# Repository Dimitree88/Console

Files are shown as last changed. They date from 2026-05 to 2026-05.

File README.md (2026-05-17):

# CONSOLE — Reference Specification

> Analog mixing console design — full signal-flow reference and
> implementation record. This is a multi-file documentation project;
> this README is the entry point.
>
> **For Claude sessions:** working rules and session-start procedure
> live in `CLAUDE.md`, which is loaded automatically.

---

## What this project is

CONSOLE is a fully analog mixing console. 24 mono input channels,
**4 stereo AUX returns**, 3 stereo groups, 4 AUX masters, CUE master,
Main Mix master with parallel SSL-style bus compression, monitor
section with AFL/PFL solo logic.

Firmware is out of scope; this documents the analog signal flow and
the implementation decisions made during circuit design.

---

## Mental model (one paragraph)

CONSOLE is a 24+4+3 analog desk (24 mono channels, 4 stereo AUX
returns, 3 stereo sub-groups) feeding a Main stereo bus with
parallel SSL-style compression. Channel strips follow a conventional
flow (balanced in → gain → HPF → insert → meter and PFL taps →
MUTE electronic switch → fader → +10 dB post-amp → pan → routing)
with two distinctive design choices: (1) dual balanced inputs A/B
with a full-differential Channel Output from Input A for ADC tracking;
(2) every channel has 4 AUX sends implemented as dual-gang pots that
simultaneously drive a pre-fader and a post-fader mono bus, giving
8 AUX buses total. The 4 stereo AUX returns are routing-only
(no Post-Fader Output to the outside, no Insert, no AUX send) — they
contribute only to internal buses (Main / Groups / AFL / CUE / PFL
stereo). Groups offer per-AUX split-or-mono mode switches so a
stereo group can feed stereo AUX pairs either as L/R split or as
mono premix. The master section's distinguishing features are the
parallel compression on the main bus (dry fader + SSL-style
compressor + wet fader → summed output) and an "in front balance"
pot that mixes an attenuated main mix behind the AFL so the engineer
always hears the context. Digital control is limited to hard-muting /
enabling electronic switches for ACTIVE, SOLO, and AFL — no VCAs,
no recall, no automation. Talkback, tone oscillators, and master
master meters are deliberately absent.

---

## File map

| File | Contents |
|---|---|
| `CLAUDE.md` | working rules for Claude — required reading at session start, loaded automatically |
| `README.md` | this file — entry point, file map, project status snapshot |
| `00-conventions.md` | design conventions + electrical/implementation conventions (power supplies, grounds, packages, default audio opamp, default topologies for EMI filter, impedance-balanced output, switches+LEDs, …) |
| `01-bus-inventory.md` | enumeration of every bus in the console (stereo + mono) and what feeds each one |
| `02-mono-channel.md` | §2 — mono input channel signal flow + Implementation details (Blocks 1, 2, …) |
| `03-aux-return.md` | §3 — stereo AUX returns (×4, identical) |
| `04-group.md` | §4 — stereo groups (×3) |
| `05-aux-master.md` | §5 — AUX master (×4) |
| `06-cue-master.md` | §6 — CUE master |
| `07-main-mix.md` | §7 — Main Mix master + parallel compression |
| `08-monitor.md` | §8 — Master monitor section |
| `09-not-present.md` | §9 — features deliberately NOT in CONSOLE |
| `10-open-tbd.md` | §10 — items deliberately unresolved at this stage |
| `11-digital-io.md` | §11 — running count of relays, LEDs, and pushbuttons; keep in sync with design changes |

(Sections §11 "Counts" lives at the end of `01-bus-inventory.md`.
The one-paragraph mental model lives at the top of this README.)

---

## Section file structure

Every main section file (`02-mono-channel.md` through `08-monitor.md`)
contains both the **conceptual signal flow** description and an
**Implementation details** subsection. Implementation details grow
over time as concrete circuit choices are made, organized into
"Blocks" (Block 1, Block 2, …) corresponding to chunks of the
signal path that were finalized in a single conversation. The Block
template and editing rules live in `CLAUDE.md`.

---

## Project status snapshot

(Update this section briefly at the end of major conversations, so
future Claude can immediately see where things stand.)

- Mono channel: signal flow conceptually complete. Implementation:
  - Block 1 (input stage → SOURCE switch + DIRECT OUT
    SELECT relay on input PCB) FINALIZED — SOURCE
    relay-driven (AGQ210A03 latching) with momentary pushbutton +
    firmware bipolar pulse; primary motivation: enables global
    master A/B flip across all 24 channels. Channel Output SELECT
    relay added: makes the Channel Output TRS jack switchable between
    Input A full-differential and channel PRE/POST impedance-
    balanced signal (see Block 8).
  - Block 2 (HPF + Insert Send/Return + jack PCB) FINALIZED.
  - Block 3 (meter buffer concept + PFL switch + MUTE) FINALIZED —
    MUTE relay (AGQ210A03) now configured **series + shunt** (contact
    set 1 = series switch, contact set 2 = shunt PRE-FADER to AGND
    when muted), replacing the earlier paralleled-contacts approach.
    Meter buffer implementation (NE5532 + DG419) finalized in Block 10.
  - Block 4 (pre-fader node + fader PCB + post-fader amp +10 dB +
    AUX/CUE pre & post sends) FINALIZED.
  - Block 5 (active pan, Self-style) FINALIZED — Self canonical
    values (R_FB = 2.2 kΩ, center dip ≈ 4.5 dB).
  - Block 6 (post-pan 2-gang × 4-pos routing rotary) topology
    defined; bus summing resistor values TBD together with §04 / §07.
  - Block 7 (AFL switch) FINALIZED — tap at post-pan opamp output;
    NC to AGND (constant termination, click-free); NO to AFL bus.
    Summing resistor values deferred to §08.
  - Block 8 (OUT-PRE/POST switch + switchable Channel Output)
    IN-PROGRESS — 75R taps from pre-MUTE and POST-FADER nodes;
    mechanical PRE-POST selector; 2-pin connector to input PCB;
    Channel Output SELECT relay on input PCB. Front-panel control:
    latching DPDT pushbutton ("DIR/PROC"), sec. 2 → indicator LED
    (LED chain confirmed). Sec. 1 → digital/driver board; MCU GPIO
    or direct-to-driver TBD (see `10-open-tbd.md`). Cold dummy
    network TBD.
  - Block 10 (dual meter buffers) FINALIZED — SOURCE relay
    contact set 2 (wired complementary to set 1) delivers the
    inactive receiver directly to the meter buffer, no additional
    electronic switch; TL072 dual JFET opamp buffers active
    (pre-MUTE) and inactive meter signals; 3-pin connector to meter
    bridge PCB. SOURCE LEDs now MCU GPIO driven (+2 GPIO
    output per channel vs. relay-contact).
- AUX returns: 4 channels, all identical, conceptual stage. ACTIVE
  and AFL switching elements fixed as AGQ210A03 (1 relay
  per function, handling L+R on its two contact sets).
- Groups: same — ACTIVE and AFL fixed as AGQ210A03.
- Master monitor: source-select (§8.1) and Solo summer AFL/PFL
  alternation (§8.2) fixed as AGQ210A03. Other stages still
  conceptual.
- All other sections (AUX/CUE/Main masters): still conceptual.
- Global conventions: established (power, grounds, packages, default
  audio opamp **NE5532**, **standard signal relay
  AGQ210A03** (Panasonic, 1-coil latching, 3 V coil), EMI filter,
  sleeve termination, impedance-balanced output topology,
  front-panel switches with LEDs, per-PCB local bulk decoupling on
  power rails). Selective upgrade to OPA1642 / OPA1656 in specific
  positions is identified as a budget-review item — see
  `10-open-tbd.md`.
- Relay infrastructure: coil supply rail settled (+3.3 V direct);
  driver partitioning settled (per-PCB stackable two-board pattern
  per `00-conventions.md` — audio PCB carries only the relay coil
  via a 3-pin connector, lower stackable PCB carries all logic).
  Total relay count: **112** (24 channels × 4 + 4 AUX returns × 2 +
  3 groups × 2 + 2 master monitor). Coil bipolar driver IC and
  master-output hard-mute for firmware boot init still tracked as
  design-phase open issues in `10-open-tbd.md`.
- Fader PCB partitioning: settled at **2 channels per fader PCB**
  (12 fader PCBs total). Input PCB partitioning still TBD.
- Front-panel channel buttons (§2.11): defined — 4 pushbuttons per
  channel: SOURCE (Pattern B, relay-contact LED), plus
  ACTIVE (orange), SOLO (red), REC (red) all Pattern C
  (integrated LED, MCU GPIO in + out). SOLO drives AFL relay + SIP
  option; REC MIDI-only, no audio relay. Per-channel digital
  I/O: 4 GPIO inputs (buttons) + 3 GPIO outputs (LEDs) +
  relay coil drivers via dedicated ICs.

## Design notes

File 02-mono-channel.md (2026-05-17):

# 02 — Mono Input Channel (× 24)

Signal flow, top-to-bottom, followed by Implementation details
(Block 1, Block 2, …).

---

## 2.1 Input stage (balanced, dual)

Two independent balanced inputs on TRS:

- **Input A** — intended for instruments (DI / mic-level-ish). Balanced
  TRS.
- **Input B** — intended for DAW return (DAC output). Balanced TRS.

Each input has:

1. **Differential buffer** — two high-Z buffers, one for hot, one for
   cold (forms the first half of the receiver).
2. **Unbalancing stage** — converts hot/cold to single-ended.
3. **Variable gain stage** — the unbalancing and gain are combined in a
   single balanced-receiver topology (see §2.10 Block 1). Each input
   (A and B) has its **own independent gain pot** — they are not
   ganged.

**Channel Output** (TRS jack on input PCB): its default output is the
full-differential signal from the two Input A buffers (before the
unbalancing stage). A firmware-controlled relay (**Channel Output SELECT**,
on the input PCB) can switch this jack to instead output an
impedance-balanced signal from the channel PCB — either pre-MUTE or
post-fader, depending on the **OUT-PRE/POST** mechanical switch on
the channel strip (see §2.9 (e)).

Note: in the Input-A state (RESET / default), the Channel Output is fully
differential (both lines actively driven from Input A buffers) —
not merely impedance-balanced. In the Channel-signal state (SET), the
output is impedance-balanced (hot = channel PRE/POST through 75 Ω;
cold = 75 Ω dummy to AGND). See Block 1 and Block 8 for implementation
details.

---

## 2.2 SOURCE switch (A / B select)

A **relay-driven electronic switch** (DPDT 2 form C, **1-coil
latching**, standard signal relay per `00-conventions.md`) selects
which of the two unbalanced-and-gained signals continues down the
channel. Only one at a time. Named **SOURCE** to avoid
confusion with the master Monitor section (`08-monitor.md`).

The front-panel control is a **momentary pushbutton** (single
contact). Firmware reads each press and issues either a set or
reset pulse (≥ 10 ms) to the relay coil, toggling the relay's
mechanically latched state. The relay's two form-C contact sets
both carry audio signals:

- **Contact set 1** — switches the **active** audio signal (A or B
  onto the channel path). NC = Receiver A (RESET default); NO =
  Receiver B.
- **Contact set 2** — switches the **inactive** receiver output to
  the meter buffer (see §2.5.1 and Block 10). Wired complementary
  to set 1: NC2 = Receiver B; NO2 = Receiver A; COM2 = inactive
  meter buffer input. In RESET state (A active on channel), set 2
  delivers Receiver B to the meter; in SET state (B active on
  channel), set 2 delivers Receiver A.

Front-panel indicator LEDs (A-LED red, B-LED green) are driven by
**MCU GPIO outputs** — firmware knows the relay state because it
commands it, and updates the LEDs on each SOURCE toggle.
Boot default: A-LED on, B-LED off (A selected, RESET state).

---

## 2.3 HPF / INSERT chain

The HPF and INSERT stages form a switchable chain that can be bypassed
as a unit by the **FX-FOLLOW relay** (§2.3.1 below). The
individual HPF switch (§2.3.2) and INSERT switch (§2.3.3) remain and
operate independently within the chain.

### 2.3.1 HPF / INSERT bypass relay

A **DPDT relay** (standard AGQ210A03, firmware-controlled, per
`00-conventions.md`) is interposed between the SOURCE relay
output and the rest of the channel. It either routes the signal through
the HPF / INSERT chain (NO contacts) or bypasses it entirely
(NC contacts):

- **COM1** — SOURCE relay output.
- **NC1 ↔ NC2** — hard-wired together. In the RESET / NC state the
  signal passes COM1 → NC1 → NC2 → COM2, bypassing the chain.
- **COM2** — the pre-MUTE node: feeds the meter buffer, PFL tap, and
  MUTE relay COM1 (see §2.5 and §2.6). Also the PRE tap for the Output
  PRE-POST switch (see §2.9 (e)).
- **NO1** — input of the HPF switch (§2.3.2 Section 1). Chain entry
  point.
- **NO2** — output of the Insert Return receiver (post-C38, §2.3.3).
  Chain exit point.

In the SET / NO state the signal path is: COM1 → NO1 → [HPF switch →
HPF → INSERT switch → Insert Return] → NO2 → COM2. The individual
switches within the chain remain fully functional.

**Front-panel control:** a momentary **pushbutton** (MCU GPIO input)
cycles through three modes, each indicated by one of three separate
**orange LEDs** (MCU GPIO outputs):

| LED | Mode | Relay behaviour |
|---|---|---|
| FOLLOW PATH (center) | Chain always in path | Relay always SET (NO) |
| FOLLOW A | Chain follows source A | SET when SOURCE = A; RESET when B |
| FOLLOW B | Chain follows source B | SET when SOURCE = B; RESET when A |

Mode cycling logic and boot state are firmware decisions — TBD, see
`10-open-tbd.md`.

### 2.3.2 HPF

Switchable **fixed-frequency high-pass filter** with a characteristic
voicing (resonant peak before the rolloff, see §2.10 Block 2). The HPF
stage is always powered; a DPDT mechanical switch (front-panel) selects
between the unfiltered and filtered signal path. The DPDT's second
section drives an **orange LED** indicating HPF IN.

### 2.3.3 Insert

Send/return insert point.

- **Send** — always active, impedance-balanced TRS jack. Taps the
  signal after HPF, before the INSERT switch.
- **Return** — switchable. TRS jack, balanced receiver (single-opamp
  4-resistor topology), unity gain.
- **Insert switch** — DPDT mechanical, front-panel. Section 1 alternates
  the onward signal between:
  - the send tap (i.e., return path bypassed), OR
  - the return input (i.e., external device in the insert loop).
  Section 2 drives a **blue LED** indicating INSERT IN.

The send and return TRS jacks live on a separate small PCB (the "jack
PCB"). The channel PCB and jack PCB are connected by a 5-pin
connector — see §2.10 Block 2 for pin assignment.

---

## 2.5 Pre-mute taps

The pre-MUTE mono signal (output of the HPF/INSERT bypass relay, COM2)
feeds two parallel taps before reaching the MUTE switch.

### 2.5.1 Meter buffers (dual bargraph)

The channel feeds **two bargraph signals** to the meter bridge PCB:

- **Active meter** (full brightness): taps the pre-MUTE node
  (HPF/INSERT bypass relay COM2). Shows the signal currently in the
  channel path, regardless of SOURCE selection.
- **Inactive meter** (dimmed on the meter bridge): taps whichever
  receiver output (A or B) is NOT currently selected by CHANNEL
  SOURCE. A CMOS SPDT switch selects between Receiver A and Receiver B
  outputs dynamically.

Both signals are buffered by unity-gain opamps on the channel PCB
and sent via a 3-pin connector to the meter bridge PCB (rectifier,
log amp, LED driver ICs, and meter LEDs all on the meter bridge, not
on the channel PCB). Neither tap interrupts the main path. Dimming
of the inactive bargraph is a meter bridge design decision.

### 2.5.2 PFL switch

A pre-fader, **pre-mute** tap to the PFL mono bus. The signal
encounters a series resistance and then the pole of a DPDT
mechanical front-panel switch.

- **Section 1** (audio): alternates the resistor's far end between
  AGND (PFL OFF) and the PFL mono bus (PFL ON). The upstream node
  sees a fixed light load identical in OFF and ON, so no DC step on
  switching → click-free.
- **Section 2** (control): pole = +3.3 V (LED rail per §00). In
  PFL ON, drives a **red front-panel LED** AND contributes via a
  wired-OR diode to the **PFL DETECT logical bus** that firmware
  monitors to drive the master monitor source-select (§8.1).

PFL listen therefore continues to work even when the channel is
muted by the MUTE switch downstream — coherent live-sound semantics
("pre-fader listen always tells you what is at the channel
input").

---

## 2.6 ACTIVE / SOLO electronic switch (MUTE)

An **electronic switch** (standard latching signal relay per
`00-conventions.md`) controlled by digital logic interrupts the main
signal path. Configured as **series + shunt**: one contact set opens
the series path when muted; the other simultaneously shunts the
PRE-FADER node to AGND. Referred to as the **MUTE relay**.

This relay is commanded by three sources:

- **ACTIVE button** on this channel (Pattern C, orange LED —
  see §2.11): toggles this channel between ACTIVE (relay RESET) and
  MUTED (relay SET).
- **SOLO logic** from any other channel: when another channel's
  SOLO is engaged in SIP (Solo In Place) mode, firmware drives
  this relay to SET (muted). Restored when the SOLO is cleared.
- **Global MUTE ALL** command from firmware (e.g. master button).

The output of this switch is the **PRE-FADER node** — source of all
post-mute pre-fader taps (CUE, AUX gang 1) and of the fader itself.

---

## 2.7 Fader + post-fader amp

- **Fader** — standard linear or log-audio mono fader.
- **Post-fader amp** — +10 dB fixed gain to recover headroom after
  the fader attenuates.

---

## 2.8 Active pan

**Active pan** circuit driven by a **dual-gang pot** (two gangs on
one shaft, reverse-wired with respect to each other so that opposite
ends of the two pot tracks see the input signal). The channel
**becomes stereo from this point on**: two lines (L and R) travel
together for the rest of the channel.

---

## 2.9 Post-pan distribution

From the post-pan stereo signal, several destinations tap in parallel:

### (a) 2-gang × 4-position rotary switch — main destination

Routes the post-pan stereo signal to exactly one of:

- Main Mix
- Group 1
- Group 2
- Group 3

Mechanical rotary, 2 gangs (one for L, one for R), 4 positions. The
inactive positions are open (not back-grounded — see Block 6 for
rationale). Only one destination at a time.

### (b) AFL electronic switch

Parallel tap, stereo. A relay-driven electronic switch (one
standard latching signal relay per channel per `00-conventions.md`
— DPDT 2 form C, 1-coil latching) connects the channel's stereo
post-pan signal to the AFL bus when the AFL logic calls for it.
Contact set 1 carries L, contact set 2 carries R; both ganged on
the same coil so L and R are perfectly synchronous.

*Tap location and reset-state direction are now fixed: tap is at the
post-pan opamp output (Block 5), through per-side bus summing resistors
(value TBD) to COM; NC contacts connect to AGND (constant termination
when AFL off — prevents impedance steps on switching, click-free); NO
contacts connect to AFL Left / AFL Right bus. Summing-resistor values
deferred to §08 — see `10-open-tbd.md`. See Block 7 for implementation
details.*

### (c) 4 × AUX dual-gang pots (mono sends)

Four knobs, each a dual-gang pot:

- **Gang 1** is fed by the **PRE-FADER node** (mono, after the
  ACTIVE/SOLO switch but before the fader). Its wiper feeds
  **AUX n PRE** bus via a bus summing resistor.
- **Gang 2** is fed by the **POST-FADER node** (mono, after the
  post-fader amp, before the pan). Its wiper feeds **AUX n POST**
  bus via a bus summing resistor.

Result: each AUX knob simultaneously drives a pre-fader and a
post-fader mono bus. 4 knobs × 2 gangs = 8 mono AUX buses.

**Note on channel-as-source vs. mono AUX bus**: the AUX sends are
taken before the pan stage. The pan would split L/R at constant
power, but since AUX buses are mono, splitting and re-summing would
just give the source back; tapping pre-pan saves the operation.

### (d) CUE dual-gang pot (stereo send)

Similar to an AUX send, but:

- Both gangs are tapped **pre-fader** (mono signal).
- The two gangs feed CUE L and CUE R of the stereo CUE bus.
- Because the source is mono, the same signal goes to both L and R
  (essentially a mono pan-center contribution into the stereo CUE
  bus).

### (e) PRE-POST output tap and OUT-PRE/POST switch

Two signal taps are taken from the channel PCB for routing to the input
PCB (to feed the switchable Channel Output — see §2.1):

- **PRE tap**: pre-MUTE signal (output of the HPF/INSERT bypass relay,
  COM2), through a **75 Ω** series resistor (branch tap; not in series
  with the main signal path).
- **POST tap**: POST-FADER node (after post-fader amp, before pan),
  through a **75 Ω** series resistor (branch tap).

A front-panel **DPDT mechanical switch** named **OUT-PRE/POST**
selects which of the two 75 Ω outputs continues to the input PCB:

- Section 1 (signal): common feeds the 2-pin connector (below);
  throws select PRE or POST 75 Ω tap output.
- Section 2 (indicator): drives two front-panel LEDs — one per
  position — from +3.3V / DGND per `00-conventions.md`. Colors TBD.

A **2-pin connector** carries the selected signal from the channel PCB
to the input PCB:

- Pin 1: the selected signal (hot, already through the 75 Ω build-out).
- Pin 2: a dedicated **75 Ω to AGND** cold dummy (provides the cold
  leg of an impedance-balanced link; full cold dummy network details
  per `00-conventions.md` standard — 47 µF ‖ 47 kΩ — TBD,
  see `10-open-tbd.md`).

On the input PCB, these lines feed the **Channel Output SELECT** relay
(Block 8), which alternates the Channel Output TRS jack between Input A
buffers and this channel signal.

*See Block 8 for implementation details.*

*(Note: the PFL switch was previously listed here as item (e). It
has been moved to §2.5.2 because the design now taps PFL pre-mute,
not post-mute.)*

---

## 2.10 Implementation details

Status: **in-progress** — Block 1 (input stage to SOURCE
switch + Channel Output SELECT relay on input PCB) FINALIZED. Block 2
(HPF + Insert Send/Return + jack PCB — now in the NO loop of Block 9),
Block 3 (meter buffer + PFL switch + MUTE, now series+shunt), Block 4
(pre-fader node + fader PCB + post-fader amp + AUX/CUE sends), and
Block 5 (active pan) finalized. Block 6 (post-pan routing rotary)
topology defined, values TBD. Block 7 (AFL switch) finalized — topology
fixed, summing resistor values deferred to §08. Block 8 (Output
PRE-POST switch + switchable Channel Output) in-progress — see
`10-open-tbd.md`. Block 9 (HPF/INSERT chain bypass relay) in-progress
— relay wiring established, logical modes and boot state TBD.
Block 10 (dual meter buffers: TL072 dual buffer, SOURCE relay
contact set 2 for inactive source selection) FINALIZED.

### Block 1 — Input stage, buffers, Channel Output, balanced receivers, SOURCE switch (FINALIZED)

**Status:** finalized

#### Topology chosen

*Input EMI filter* (× 2 inputs per channel: A and B, each with hot +
cold):

- T-balanced double-pi filter per global standard
  (see `00-conventions.md`).

*Input jack idle-noise scheme:*

- The TRS jacks for Input A and Input B are *stereo with switch*
  type (5 contacts: TIP, RING, SLEEVE, TIP-SW, RING-SW). TIP-SW and
  RING-SW are tied together but otherwise unconnected. When no plug
  is inserted, the jack's mechanical normalling closes TIP-SW onto
  TIP and RING-SW onto RING — therefore TIP↔RING are shorted at the
  jack itself in idle. The All-Inverting receiver downstream sees
  zero differential signal at idle, eliminating differential pickup
  on open inputs. SLEEVE remains permanently to chassis (Pin 1
  rule). With a plug inserted, the SW contacts open and balanced
  operation is fully restored. Common-mode pickup at idle is left to
  the receiver's CMR, deemed sufficient.

*Buffer stage:*

- One **OPA1679** (quad SOIC) per channel serves all 4 buffers (A-hot,
  A-cold, B-hot, B-cold), each wired as unity-gain voltage follower.
- Input DC block: 47 µF bipolar electrolytic in series, 100 kΩ to AGND.
- The 4 buffer outputs leave the input PCB via a 5-pin connector
  (4 signals + AGND centered).

*Channel Output* (Input A only, TRS rear-panel jack):

- Tap from the two buffer outputs of Input A (hot and cold), driven
  actively on both lines.
- **Build-out resistors: 75 Ω 0.1 % thin-film matched pair**, one
  per leg (hot and cold), in series between each buffer output and
  the EMI filter. The build-out is on the Channel Output branch only;
  the internal off-board path to the next PCB (toward the
  All-Inverting receiver) does NOT carry build-out, since the
  receiver wants Z_source ≈ 0 and the two opamps of the same quad
  are intrinsically matched.
- Same T-balanced EMI filter topology as the input
  (see `00-conventions.md`).
- **No DC block** between buffer output and the TRS jack. OPA1679
  V_os ≤ ±1.5 mV / section, differential offset ≤ ~3 mV — negligible
  for any downstream balanced receiver. A series cap on each leg
  would degrade CMR at low frequencies (electrolytic tolerance
  produces ΔX_c that translates to ΔZ_source) exactly where mains
  hum sits. Trade favors omitting the cap.
- Note: the Channel Output is "fully-balanced" only if the source driving
  the TRS input is itself balanced; if the source is
  impedance-balanced or single-ended, the Channel Output preserves that
  same character. The §2.1 wording "full-differential" should be read
  as "both lines are actively driven by a buffer", not as "a
  differential feedback forces hot = −cold".

*Channel Output SELECT relay (§2.1):*

- **AGQ210A03** (DPDT 2 form C, 1-coil latching signal relay, per
  `00-conventions.md`) on the input PCB, interposed between the
  75 Ω build-out resistors and the Channel Output EMI filter.
- **NC / RESET state (Input A — default):** contact set 1 COM →
  Input A hot 75 Ω build-out → EMI filter tip; contact set 2 COM →
  Input A cold 75 Ω build-out → EMI filter ring. Original
  full-differential behavior.
- **NO / SET state (Channel signal):** contact set 1 COM → pin 1
  of 2-pin connector (channel PRE/POST signal) → EMI filter tip;
  contact set 2 COM → pin 2 of 2-pin connector (cold dummy 75 Ω)
  → EMI filter ring. Impedance-balanced behavior.
- See Block 8 for full wiring and decisions.

*Balanced receivers — "All Inverting" topology* (Jung/Kester Fig. 6-26,
Op Amp Applications Handbook):

- Two receivers per channel, one for Input A, one for Input B.
- Each receiver uses 2 opamps → 4 opamps per channel → one **OPA1679**
  (quad SOIC) hosts both receivers.
- **U1** (first opamp of the pair): inverting unity-gain inverter.
  - Input: hot line via 1 kΩ to inverting input; non-inv to AGND.
  - Feedback: 1 kΩ.
  - Output: −Vhot.
- **U2** (second opamp of the pair): inverting summing amplifier.
  - Inputs: −Vhot (from U1) via 1 kΩ, and cold line via 1 kΩ, both to
    inverting input; non-inv to AGND.
  - Feedback: 100 Ω (fixed minimum) in series with 10 kΩ log pot,
    used as a 3-terminal resistor (wiper + unused end strapped
    together for fail-safe behavior on wiper discontinuity).
  - Output: +(Vhot − Vcold) × Rf / 1 kΩ.
- Gain range per receiver: **G = 0.1 (−20 dB) to 10.1 (+20 dB)**,
  ≈ 40 dB total, pseudo-log taper.
- CMR depends only on matching of the four 1 kΩ resistors per
  receiver. The feedback Rf (pot) does **not** affect CMR — a defining
  property of this topology that justifies using a pot for gain
  control.

*Post-receiver DC block* (per receiver output, × 2 per channel):

- 47 µF bipolar electrolytic in series.
- 47 kΩ to AGND (bias path for the switch pole + discharge path for
  the unselected branch, avoiding click on A↔B switching).
- fc ≈ 0.072 Hz — effectively just a DC block in audio band.

*SOURCE switch:*

- **AGQ210A03** (DPDT 2 form C, 1-coil latching signal relay,
  standard signal relay per `00-conventions.md`). See §2.2.
- Front-panel control: momentary pushbutton (single contact). Each
  press is read by firmware, which issues a set or reset pulse
  (≥ 10 ms) to the coil's bipolar driver, toggling the latched
  state.
- Contact set 1 (audio — active channel): COM = onward channel
  path; NC = Receiver A output (post-DC-block); NO = Receiver B
  output (post-DC-block). In RESET state, Receiver A is selected
  (firmware-initialized boot default).
- Contact set 2 (audio — inactive meter): COM = inactive meter
  buffer input (TL072 half 2 — see Block 10); NC = Receiver B
  output (post-DC-block); NO = Receiver A output (post-DC-block).
  Wired complementary to set 1: in RESET state (A active), COM2
  delivers Receiver B to the meter; in SET state (B active), COM2
  delivers Receiver A. No additional electronic switch needed.
- A-LED (red) and B-LED (green): MCU GPIO outputs, updated by
  firmware on each SOURCE toggle. Boot default: A-LED on,
  B-LED off.
- Coil drive: bipolar pulse from a 3 V coil supply per
  `00-conventions.md` "Standard signal relay". Driver IC and
  partitioning TBD — see `10-open-tbd.md`.

#### Active devices

**OPA1679 × 2 per channel:**

- 1× for buffers (4 opamps used).
- 1× for balanced receivers (4 opamps used).

**AGQ210A03 × 1 per channel** (DPDT 2 form C, 1-coil latching
signal relay): SOURCE A/B select. Per `00-conventions.md`
"Standard signal relay".

**AGQ210A03 × 1 per channel** (DPDT 2 form C, 1-coil latching
signal relay): Channel Output SELECT (Input A vs channel PRE/POST).
Per `00-conventions.md` "Standard signal relay". See Block 8.

#### Key passive values

- Receiver matched resistors: 1 kΩ × 4 per receiver × 2 receivers =
  **8 per channel — CMR-critical**. Target tolerance: **0.1 %
  thin-film**.
- **Channel Output build-out: 75 Ω × 2 per channel** (hot and cold of
  Input A only). **0.1 % thin-film matched pair**, same lot for
  thermal tracking.
- Gain pot: 10 kΩ log × 2 per channel (one per input, independent).
- Pot minimum series: 100 Ω × 2 per channel.
- A-LED (red) and B-LED (green) current-limit resistors on the
  SOURCE indicator (MCU GPIO driven): TBD (depends on
  chosen LED Vf and brightness target).
- Coil protection (flyback / freewheeling network for bipolar
  drive): exact topology TBD with the coil driver choice.

#### Design targets / expected performance

- Zin (balanced, differential): ≈ 200 kΩ.
- Gain range: −20 dB to +20 dB, pot-controlled, log taper.
- CMR: ≥ 60 dB target with 0.1 % matched 1 kΩ.

#### Decisions and tradeoffs

- **Two independent gain pots** (one per Input A, one per Input B)
  instead of a shared stereo pot. Reason: A and B typically have very
  different working levels.
- **All-Inverting receiver over other topologies.** Reason:
  single-resistor gain change with no CMR interaction.
- **No phase-lead compensation on the receivers (first revision).**
  Footprints provided but unpopulated; populate in rev 2 if measured
  10 kHz CMR is insufficient.
- **OPA1679 (CMOS quad) over the global NE5532 default.**
  Documented exception per `00-conventions.md`. Three reasons combine
  to justify the deviation here:
  (1) buffer count: 4 buffers + 4 receiver opamps per channel = 8
  opamps, naturally fitted by 2 quads.
  (2) the input-side buffer sits at very high source impedance
  (200 kΩ shunt to AGND); a bipolar opamp's bias current (~200 nA
  for NE5532) would drop ~40 mV across the input bias resistor and
  must be matched between hot and cold legs to preserve CMR — the
  CMOS ~10 pA bias current sidesteps this.
  (3) the Channel Output path runs without a DC block (see above);
  OPA1679's low Vos keeps the cumulative offset within budget for
  any downstream ADC differential input.
- **Channel Output build-out: 75 Ω 0.1 % matched pair**, on hot and cold,
  on the Channel Output branch only. Trades a small CMR floor (≈ 96 dB
  with 0.1 % matching, well below the receiver's CMR ceiling) for
  cable-capacitance isolation, short-circuit protection, and proper
  source impedance for the EMI filter — the build-out becomes the
  source impedance against which the π-stage attenuates; without it,
  the filter loses HF attenuation due to near-zero source Z.
  Internal off-board path to the All-Inverting receiver stays at
  Z_source ≈ 0.
- **No DC block on the Channel Output path.** OPA1679 V_os is small
  enough that a series cap is not needed and would actively hurt
  CMR at low frequencies (electrolytic tolerance ⇒ ΔX_c ⇒ ΔZ_source
  exactly where mains hum lives). See *Channel Output* in Topology
  chosen for the numbers.
- **TIP-SW = RING-SW shorting on Input A and B jacks.** Exploits
  the jack's normalling contacts to short TIP↔RING when no plug is
  inserted, so the receiver sees zero differential signal at idle.
  See *Input jack idle-noise scheme* in Topology chosen.
- **LED power on +3.3V / DGND**, galvanically separate from audio
  ±15V / AGND.
- **SOURCE as relay-driven electronic switch** (AGQ210A03
  latching signal relay, both contact sets for audio — set 1 for
  active channel, set 2 for inactive meter — ganged on one coil)
  instead of a direct mechanical DPDT. Primary reason: the relay
  approach is directly compatible with a **global master A/B flip**
  — firmware can toggle every channel's SOURCE relay
  simultaneously, routing all 24 channels from DAW (B) to
  instruments (A) or vice versa in one command. Contact set 2,
  wired complementary to set 1, delivers the inactive receiver to
  the meter buffer with no additional electronic switch. State is
  held mechanically (latch), contact resistance ≤ 100 mΩ initial.
  Boot default = A (RESET state, NC contacts); this is a
  firmware-init contract, not a hardware property. Per
  `00-conventions.md` "Standard signal relay".

---

### Block 2 — HPF + Insert Send/Return + jack PCB (FINALIZED)

**Status:** finalized — this block describes the circuitry within the
NO loop of the HPF/INSERT bypass relay (Block 9). The entry point is
NO1 of that relay; the exit point is NO2.

#### Topology chosen

*HPF (§2.3):*

- Cascade of a passive 1st-order HPF and an active Sallen-Key
  2nd-order HPF, unity gain. Topology copied from another mixer
  (specific source not recorded; circuit accepted as-is).
- Passive 1st-order: C39 (220 nF) in series, R23 (5.1 kΩ) to AGND.
  fc ≈ 142 Hz.
- Active Sallen-Key 2nd-order: C40 (220 nF) in series with R24
  (1.3 kΩ) bootstrap to opamp output, C41 (220 nF) to opamp non-inv,
  R25 (62 kΩ) from non-inv to AGND. Opamp wired as unity-gain
  follower (inv pin directly connected to output).
  - f0 ≈ 80.6 Hz, **Q ≈ 3.46**.
- Output DC block: C42 (47 µF bipolar) in series, R26 (47 kΩ) to AGND.
- Opamp: **NE5532 IC2B** (dual SOIC). The other half (IC2A) is used
  by the Insert Return receiver.
- HPF stage is **always powered**. The DPDT switch only selects which
  signal continues downstream (unfiltered or filtered).

*HPF switch:*

- DPDT mechanical, front-panel.
- Section 1: alternates between unfiltered (NO1 of the HPF/INSERT
  bypass relay, Block 9) and HPF output (post-C42).
- Section 2: drives **orange LED**, on when HPF IN, +3.3V / DGND.

*Insert Send (§2.4):*

- Branch tap taken at the HPF output side (post-C42, post DC-block),
  upstream of the INSERT DPDT switch. The Send is therefore always
  active regardless of INSERT switch position.
- The branch goes through 75 Ω in series → pin 4 of the 5-pin
  connector to the jack PCB.
- The cold dummy network (built on the channel PCB, on pin 5 of the
  connector): 75 Ω in series, followed by a node with 47 µF to AGND
  in parallel with 47 kΩ to AGND. Per the global default
  (see `00-conventions.md`).

*Insert Return receiver:*

- Classic single-opamp differential receiver, 4-resistor topology.
- Hot line: C34 (47 µF bipolar, DC block) → R18 (10 kΩ) → opamp inv
  pin.
- Cold line: C35 (47 µF bipolar, DC block) → R19 (10 kΩ) → opamp
  non-inv pin.
- Feedback: R20 (10 kΩ) from output to inv. R21 (10 kΩ) from non-inv
  to AGND.
- HF compensation: **C36 = C37 = 100 pF NPO ±5%**, in parallel with
  R20 (feedback) and R21 (non-inv to AGND) respectively. Symmetric
  placement preserves CMR at HF. fc of HF rolloff ≈ 159 kHz — RF
  filter only, zero impact in audio band.
- Output DC block: C38 (47 µF bipolar) in series, R22 (47 kΩ) to AGND.
- Gain: **unity, fixed**.
- Opamp: **NE5532 IC2A** (the other half of the HPF opamp).

*INSERT switch:*

- DPDT mechanical, front-panel.
- Section 1: alternates onward signal between the pre-insert tap
  (post-HPF, branch upstream of the Send 75 Ω) and the Return
  receiver output (post-C38).
- Section 2: drives **blue LED**, on when INSERT IN, +3.3V / DGND.

*5-pin connector — channel PCB ↔ jack PCB:*

- Pin 1: Return hot (from jack PCB to channel PCB receiver).
- Pin 2: Return cold (from jack PCB to channel PCB receiver).
- Pin 3: AGND. Travels in the cable as a guard between Send and
  Return pin pairs to reduce intra-cable crosstalk. **On the jack
  PCB, pin 3 lands on an isolated test point** and does NOT propagate
  into any ground pour on the jack PCB (the jack PCB has only a
  chassis pour, no AGND pour).
- Pin 4: Send hot (from channel PCB, post 75 Ω, to jack PCB).
- Pin 5: Send cold (from channel PCB cold dummy network, to jack
  PCB).

*Jack PCB:*

- Two TRS jacks (Send and Return).
- Standard T-balanced double-pi EMI filter on tip and ring of each
  jack (see `00-conventions.md`).
- Sleeve of each TRS jack connected directly to the chassis pour
  (Muncy Pin 1 rule, see `00-conventions.md`).
- No AGND plane / pour on this PCB. Only chassis.

#### Active devices

**NE5532 × 1 per channel** (dual SOIC):

- IC2A: Insert Return receiver.
- IC2B: HPF (Sallen-Key + passive 1st-order).
- Rationale: shared between two functions, low part count. Per global
  default in `00-conventions.md`.

#### Key passive values

- HPF caps: C39 / C40 / C41 = 220 nF (film, low DA — final dielectric
  TBD based on physical size). C42 = 47 µF bipolar electrolytic.
- HPF resistors: R23 = 5.1 kΩ, R24 = 1.3 kΩ, R25 = 62 kΩ, R26 = 47 kΩ.
- Insert Return receiver matched resistors:
  R18 = R19 = R20 = R21 = 10 kΩ × 1 receiver per channel = **4 per
  channel — CMR-critical**. Target tolerance: **0.1 % thin-film**.
- Insert Return HF compensation: C36 = C37 = 100 pF NPO ±5%.
- Insert Return DC blocks: C34, C35, C38 = 47 µF bipolar electrolytic.
- Insert Return bias paths: R22 = 47 kΩ.
- Insert Send build-out: 75 Ω (tip series); cold dummy = 75 Ω + 47 µF
  to AGND + 47 kΩ to AGND.
- HPF / INSERT LEDs: standard low-current parts on +3.3V / DGND
  (orange and blue). **Note**: blue LED Vf is typically
  3.0–3.4 V, leaving very little headroom across the current-limit
  resistor on a +3.3 V rail. Either use a low-Vf blue (~2.7 V) or
  re-evaluate the LED color choice — see `10-open-tbd.md`.

#### Design targets / expected performance

- HPF response: 3rd-order overall (1st passive + 2nd active SK), with
  a resonant peak of approximately +5 dB around 80 Hz before rolloff
  (due to Q ≈ 3.46 on the SK stage). Not Butterworth — see open
  issues.
- Insert Return receiver: unity gain, CMR limited by matching of the
  four 10 kΩ resistors. With 0.1 % thin-film, CMR ≈ 54 dB worst case.
- HF rolloff of receiver: fc ≈ 159 kHz — transparent in audio band,
  attenuates RF residue.

#### Decisions and tradeoffs

- **HPF topology copied from existing mixer**, accepted as-is. Q ≈
  3.46 on the SK stage produces a ~+5 dB peak around 80 Hz. Not yet
  decided whether this is intentional voicing or should be rebalanced
  toward Butterworth (see `10-open-tbd.md`).
- **NE5532 dual shared between HPF and Insert Return receiver.**
  Single chip serves both functions, reducing part count. Per global
  default in `00-conventions.md`. NE5532's CM-distortion at the SK
  stage's high-Z +input is the most visible NE5532 limitation in
  this Block; identified as a candidate for selective upgrade to
  OPA1642 (JFET) at the budget-review stage — see `10-open-tbd.md`.
- **Single-opamp differential receiver on the Insert Return** (rather
  than the All-Inverting topology used on the input). Reason: simpler,
  fixed unity gain (no need for the All-Inverting's CMR-vs-gain
  decoupling property), one less opamp, the Insert Return is a less
  critical input than the channel input.
- **Insert Return: unity gain fixed**, no trim. Coherent with §2.4
  "fixed gain" wording. If a trim is needed in future revisions, the
  topology supports adding it on the feedback path.
- **HF compensation caps C36 = C37 = 100 pF NPO ±5%**: chosen to
  filter only RF residue (fc ≈ 159 kHz), no impact on audio band.
  Symmetric placement preserves HF CMR.
- **Send tap upstream of INSERT switch**: Send is always active, even
  when INSERT switch is OUT. This matches §2.4 wording.
- **Send cold dummy network placed on the channel PCB**, not on the
  jack PCB. Reason: keeps the jack PCB purely passive (only TRS jacks
  + EMI filters), and consolidates the active-side electronics on one
  board.
- **5-pin connector with pin 3 as AGND guard trace** (option A,
  decided in conversation): AGND travels in the cable to reduce
  intra-cable crosstalk between Send and Return, but lands on an
  isolated test point on the jack PCB so the jack PCB remains
  chassis-only. No ground loop possible between the two PCBs through
  this connector.
- **No EMI filter on the channel-side end of the 5-pin connector** —
  EMI filtering is concentrated on the jack PCB at the TRS jacks
  themselves, which is where RFI actually couples in.

#### Open issues for Block 2

- **HPF voicing**: Q ≈ 3.46 is high (resonant peak ~+5 dB at 80 Hz).
  To revisit later: confirm intentional voicing or rebalance toward
  Butterworth (Q ≈ 0.7, R24 → ~31 kΩ). See `10-open-tbd.md`.
- **Send cold dummy network impedance balance at low frequencies**:
  the 47 µF in the dummy has Xc ~169 Ω at 20 Hz, so Z_tip ≠ Z_ring
  below ~100 Hz. CMR of the downstream receiver degrades at low
  frequencies — exactly where mains hum lives. Possible mitigation:
  larger dummy cap (220–470 µF) or alternative topology. Default
  pattern in `00-conventions.md` reflects the current choice; revise
  if measured hum rejection on Insert is insufficient. See
  `10-open-tbd.md`.
- HPF film cap dielectric (PPS / PET / PP / NPO depending on physical
  size at 220 nF) — TBD.
- HPF switch and INSERT switch part selection (DPDT, front-panel,
  current rating adequate for LED section).
- 75 Ω resistor part / package — non-critical, 0603 1 % standard.

---

### Block 3 — Meter buffer + PFL switch + MUTE (FINALIZED)

**Status:** finalized

#### Topology chosen

*Meter buffers (§2.5.1):*

- Active meter buffer: unity-gain voltage follower. Input is the
  pre-MUTE node (HPF/INSERT bypass relay COM2). DC-free in both
  relay states: NC path — Block 1 post-receiver DC block; NO path —
  C42 or C38 (Block 2). No input DC block.
- Inactive meter buffer: unity-gain voltage follower. Input is the
  output of a CMOS SPDT switch (DG419) selecting whichever receiver
  output (A or B) is not currently on the channel path.
- Each buffer output: 75 Ω build-out → 3-pin connector to meter
  bridge PCB (pin 1 = active, pin 2 = inactive, pin 3 = AGND).
- Meter bridge PCB carries a full **AGND pour** (no TRS jacks →
  Muncy Pin 1 rule does not apply). Separate DGND pour for LEDs.
- **See Block 10 for full implementation** (DG419, NE5532,
  bypass caps, and connector details).

*PFL switch (§2.5.2):*

- 22 kΩ in series with the pre-MUTE node signal (bypass relay COM2)
  feeds the pole of a DPDT mechanical front-panel switch.
- Section 1 (audio): throws between AGND (PFL OFF) and the PFL mono
  bus (PFL ON). The 22 kΩ is the bus summing resistor for this
  channel's PFL contribution. Constant load on the upstream node in
  both positions → no DC step on switching → click-free.
- Section 2 (control): pole = +3.3 V (LED rail). In PFL ON, throws
  to a junction connecting (a) the anode of the **red front-panel
  PFL LED** (cathode to DGND via current-limit resistor) and
  (b) the anode of a small-signal diode whose cathode goes to the
  **PFL DETECT logical bus** (wired-OR HIGH ⇒ at least one PFL
  active anywhere on the console). The diode prevents back-feed of
  +3.3 V from one channel's Sec2 to another's LED via the bus.

*MUTE switch (§2.6):*

- **AGQ210A03** (DPDT 2 form C, 1-coil latching signal relay,
  standard signal relay per `00-conventions.md`).
- Audio path: **series + shunt configuration** — the two contact
  sets serve different roles (not wired in parallel):
  - **Contact set 1 (series):** COM1 = pre-MUTE node (HPF/INSERT
    bypass relay COM2 — taken upstream of the meter buffer / PFL
    tap node); NO1 = PRE-FADER node onward; NC1 = floating.
  - **Contact set 2 (shunt):** COM2 = PRE-FADER node; NC2 = AGND;
    NO2 = floating.
- **ACTIVE state (SET):** series contact closes (signal passes from
  post-INSERT to PRE-FADER); shunt contact opens (PRE-FADER not
  shunted to AGND). Normal signal flow.
- **MUTE state (RESET):** series contact opens (signal
  interrupted); shunt contact closes (PRE-FADER shunted to AGND).
  Both mechanisms act simultaneously on the single coil.
- Series contact R_on: ≈ 100 mΩ initial (single contact set).
- Coil drive: bipolar pulse from a 3 V coil supply, per
  `00-conventions.md` "Standard signal relay". Driver IC and
  partitioning TBD — see `10-open-tbd.md`.
- Logic semantics: **SET state ⇒ channel ACTIVE** (series contact
  makes, signal passes; shunt contact opens, PRE-FADER free);
  **RESET state ⇒ channel MUTED** (series contact opens, signal
  interrupted; shunt contact makes, PRE-FADER shunted to AGND).
  The relay holds its state mechanically; firmware initializes
  every MUTE relay to RESET at startup. Master-output hard-mute
  keeps the room silent until firmware completes init (master
  section, TBD).

#### Active devices

- **Meter buffer opamps**: **NE5532** (both halves used) — full
  implementation in Block 10.
- **AGQ210A03** × 1 per channel (DPDT 2 form C, 1-coil latching
  signal relay), used as the MUTE switch. Per `00-conventions.md`
  "Standard signal relay".
- **Small-signal diode** for the PFL DETECT wired-OR (1N4148-class):
  exact part TBD.
- **Coil protection** (flyback / freewheeling network for bipolar
  drive): exact topology TBD with the coil driver choice. Typically
  integrated into the chosen latching-relay driver IC.

#### Key passive values

- Meter buffer build-out: **75 Ω × 2** (0603 1 %) — see Block 10.
- PFL series / summing resistor: **22 kΩ** (0603 1 %).
- PFL LED current-limit resistor: TBD (depends on chosen LED Vf
  and desired brightness).
- Coil supply: directly from the +3.3 V logic rail per
  `00-conventions.md` "Standard signal relay" — no series
  dropping network needed.

#### Design targets / expected performance

- Meter buffer: unity gain DC–audio band, output capable of driving
  ≈100 pF cable capacitance via the 75 Ω build-out without ringing.
- MUTE switch contact resistance (series branch): ≤ 100 mΩ initial
  (single contact set). Effectively zero THD contribution (purely
  resistive, voltage-independent), no charge injection.
- MUTE off-isolation: open-contact isolation > 80 dB at 1 MHz per
  datasheet, effectively unbounded at audio. Far in excess of any
  practical channel mute requirement.
- MUTE operate / release time: ≤ 3 ms each per datasheet (no
  bounce specified beyond this figure). Adequate for hard-mute
  semantics; not used for fast gating.

#### Decisions and tradeoffs

- **Meter detection chain on a separate PCB**: pattern matches the
  jack PCB and input PCB partitioning. Allows the meter LED bridge
  to be a separate mechanical sub-assembly (the visual "meter
  bridge" at the top of a console). Two signals per channel (active
  + inactive) via a 3-pin connector.
- **Unbalanced send to meter PCB** rather than impedance-balanced
  or fully balanced: cable run is short and internal, destination
  is a rectifier (not a hi-fi amp), saves pins and parts.
- **Meter PCB AGND pour, not chassis-only**: no TRS jacks present
  on the meter PCB, so no Muncy "Pin 1" rationale to keep AGND
  isolated from chassis on that board.
- **PFL is pre-fader and pre-mute**, achieved by tapping upstream of
  the MUTE relay. PFL listen continues to work even when the
  channel is muted, matching live-sound semantics. Conceptually
  relocated out of §2.9 (post-pan distribution) into §2.5 (pre-mute
  taps).
- **22 kΩ + DPDT pattern for PFL** rather than a buffered tap:
  shared-bus summing where every active PFL contribution adds via
  its 22 kΩ at the PFL mono bus virtual-earth. The constant load on
  the upstream node (in both OFF and ON, the 22 kΩ sits between
  signal and 0 V) means no DC step on switching → click-free.
- **PFL DETECT as a separate logical bus**, fed via per-channel
  diode wired-OR from Sec2 of the DPDT. Avoids dragging analog PFL
  audio into firmware. The diode prevents inter-channel back-feed
  through the bus.
- **Latching relay (AGQ210A03) for MUTE instead of a CMOS analog
  switch.** Combined reasons: (1) signal-path quality — contact
  resistance ≤ 50 mΩ paralleled (vs ≈ 17 Ω for an ADG419-class
  CMOS), no charge injection, no CMOS distortion vs source-Z
  artefacts; (2) off-isolation effectively unbounded at audio
  through physical contact opening; (3) latching means coil power
  is consumed only during ~10 ms set/reset pulses — no continuous
  140 mW-per-energized-relay budget on the coil rail. Trade-off
  accepted: indeterminate state at power-up (firmware must
  initialize every MUTE relay to RESET / muted at boot, with a
  master-output hard-mute covering the init window — TBD, master
  section), ~ 4 ms switching time, and the need for a bipolar
  pulse driver. Per `00-conventions.md` "Standard signal relay".
- **Series + shunt configuration** for the MUTE relay, rather than
  paralleling both contact sets for lower R_on. Trade-off: series
  R_on rises from ≈ 50 mΩ (paralleled) to ≈ 100 mΩ (single contact
  set) — still negligible in the signal path. Gain: the shunt
  contact explicitly drives the PRE-FADER node to AGND when muted,
  so any residual signal leaking through the open series contact
  (contact capacitance, PCB parasitics at HF) is further attenuated
  by the shunt. Mute depth exceeds open-contact isolation alone.

#### Open issues for Block 3

- **Channels per input PCB** (4 or 6) and resulting **relay coil
  control connector partitioning** (one wide connector per PCB
  carrying SET + RESET lines per channel, vs narrower per-channel
  connectors) — TBD. See `10-open-tbd.md`.
- **Coil driver IC** for the MUTE relay (and, more broadly, for
  every AGQ210A03 in the console): bipolar / half-H-bridge per
  relay (TBD62783A + TBD62083A pair, octal latching-relay driver
  like MAX4820/4821, or per-relay discrete NPN+PNP); partitioning
  and exact part TBD. See `10-open-tbd.md`.
- **Coil supply**: from the +3.3 V logic rail (the 3 V coil
  tolerates +3.3 V — see `00-conventions.md`). Local bulk
  capacitance on the +3.3 V plane sized for the worst-case
  pulse-current transient on each PCB.
- **Other PFL sources feeding PFL DETECT**: AUX masters (§05),
  AUX returns (§03), and groups (§04) all carry PFL controls; do
  they all need to feed PFL DETECT to drive the firmware
  source-select? — TBD. See `10-open-tbd.md`.
- **PFL LED current-limit resistor value** — depends on chosen LED.
- **PFL signal diode** — 1N4148-class, exact part TBD.
- **Coil protection network** for bipolar drive — topology and
  parts TBD with the chosen latching-relay driver IC (often
  integrated). See `10-open-tbd.md`.

---

### Block 4 — Pre-fader node + fader PCB + post-fader amp + AUX/CUE sends (FINALIZED)

**Status:** finalized

#### Topology chosen

*Pre-fader node:*

The paralleled NO outputs of the MUTE relay (AGQ210A03) in Block 3
form the PRE-FADER node.
This node is loaded by three parallel paths:

- **4 × AUX dual-gang pots, pre-fader gangs (gang 1 of each).** Top
  of each pre gang to PRE-FADER, bottom to AGND, wiper drives a
  bus summing resistor toward AUX n PRE bus.
- **1 × CUE dual-gang pot, both gangs identically fed.** Top of
  both gangs to PRE-FADER, bottom of both gangs to AGND. The two
  wipers drive bus summing resistors toward CUE L bus and CUE R
  bus respectively. Topologically identical to an AUX-pre send,
  duplicated across L and R because the channel is mono and the
  CUE bus is stereo — produces a center-panned contribution on
  the stereo CUE bus, with one knob controlling level.
- **Pin 1 of a 3-pin connector** to the fader PCB (see below).

*3-pin connector — channel PCB ↔ fader PCB:*

| Pin | Direction | Signal |
|-----|---|---|
| 1 | channel → fader | PRE-FADER |
| 2 | shared | AGND (interposed as guard) |
| 3 | fader → channel | POST-FADER |

The AGND between Pin 1 and Pin 3 is intentional: Pin 1 carries the
pre-fader signal and Pin 3 carries the same signal attenuated by
the fader. Although correlated, interposing AGND prevents inter-PCB
ground potential differences from showing up at the wiper.

*Fader PCB:*

Hosts **2 channels per PCB** (12 fader PCBs total for the 24 mono
channels). Each channel uses one half of an NE5532 dual.

The fader PCB also hosts the **3 momentary pushbuttons with integrated
LEDs** for this channel: ACTIVE (orange), SOLO (red), REC
(red). Physical co-location with the fader is confirmed; electrical
connection to the digital logic PCB (GPIO routing) is TBD.

Per channel on the fader PCB:

1. **Fader** (mono, taper TBD): top lug = pin 1 (PRE-FADER), bottom
   lug = AGND (pin 2), wiper continues onward.
2. **Wiper DC block + bias**: wiper → C_bp (bipolar electrolytic,
   value TBD) in series → R_bias to AGND (value TBD) → +input of
   one half of an NE5532.
3. **Post-fader amp** (non-inverting, +10 dB nominal):
   - Inverting input: connected to a feedback node, plus R_G to
     AGND.
   - Feedback: from the FB node back to the inverting input through
     R_FB ‖ C_FB.
   - The opamp output pin drives a 680 Ω in series; the FB node is
     taken on the **far side** of the 680 Ω. R_FB ‖ C_FB closes
     back to the FB node.
4. **Output DC block**: 220 µF polarized electrolytic in series →
   pin 3 of the connector.

*Post-fader return on channel PCB:*

Pin 3 of the connector returns the POST-FADER signal to the channel
PCB. This signal feeds in parallel:

- **4 × AUX dual-gang pots, post-fader gangs (gang 2 of each).**
  Top of each post gang to POST-FADER, bottom to AGND, wiper drives
  bus summing resistor toward AUX n POST bus.
- **Top of the pan dual-gang pot** (both gangs — see Block 5).
- (later) Post-Fader Output tap — to be designed (see open issues).

#### Active devices

- **NE5532 × 1 per fader PCB** (dual SOIC; one half per channel,
  used as post-fader amp). Per global default in `00-conventions.md`.

#### Key passive values

- R_FB (post-fader amp): **4.7 kΩ** (0603 1 %).
- R_G (post-fader amp): **2.2 kΩ** (0603 1 %).
- **C_FB (HF pole on R_FB): 100 pF NPO/C0G** (0603). HF pole at
  ≈ 339 kHz.
- Series resistor inside loop: **680 Ω** (0603 1 %).
- Output DC block: **220 µF** polarized electrolytic.
- C_bp (wiper DC block, bipolar): TBD.
- R_bias (wiper to AGND after C_bp): TBD. With NE5532 (I_B ~ 200 nA),
  R_bias = 47 kΩ would produce ~9 mV DC at the +input → ~30 mV at
  the opamp output (post +10 dB), absorbed by the 220 µF output DC
  block. Final value to be set when C_bp is sized.
- 4 × AUX dual-gang pots: value TBD.
- 1 × CUE dual-gang pot: value TBD.
- 8 × AUX bus summing resistors per channel (4 pre + 4 post): TBD.
- 2 × CUE bus summing resistors per channel (L + R): TBD.

#### Design targets / expected performance

- Post-fader amp gain: **+9.93 dB** (1 + 4.7/2.2 = 3.136), nominal
  +10 dB.
- Post-fader amp HF pole: ≈ 339 kHz (R_FB ‖ C_FB). Audio-band
  response flat to within −0.015 dB at 20 kHz.
- Post-fader amp output impedance at audio: ≈ 0 Ω at the FB node
  (pulled there by feedback through R_FB; 680 Ω is inside the
  loop). At HF, where loop gain falls, the 680 Ω becomes effective
  output impedance and isolates the opamp from capacitive load /
  short-circuit conditions on the connector and 220 µF.
- Pre-fader node source impedance: ≈ 50 mΩ (parallel of two
  AGQ210A03 contacts, 100 mΩ each initial) + bias paths from the
  upstream stage (Block 3) — effectively dominated by upstream
  impedances.
- Post-fader amp drive: NE5532 is rated for 600 Ω loads at low
  distortion; the parallel load presented by 5 × 10 kΩ pot tops
  (4 AUX-post + pan) is ≈ 2 kΩ, well within capability. Verify when
  AUX/CUE/pan pot values are finalized (§05, §06).

#### Decisions and tradeoffs

- **Fader on a separate PCB hosting 2 channels.** Partitions the
  console into modular sub-assemblies aligned with the mechanical
  layout (fader bank in front of the channel strips). The 3-pin
  connector keeps the fader PCB minimal and standard across all
  channels.
- **3-pin connector with AGND interposed** between PRE-FADER and
  POST-FADER lines: prevents inter-PCB ground potential differences
  from appearing as offsets at the wiper.
- **NE5532 for the post-fader amp.** Per global default in
  `00-conventions.md`. The +input sees the wiper through C_bp:
  C_bp blocks DC, so the bipolar input bias current of NE5532
  (~200 nA) flows only through R_bias to AGND, producing a static
  DC offset at the +input independent of fader position. No
  position-dependent thump on fader movement. The 220 µF output
  DC block absorbs the resulting offset before it reaches
  downstream stages. Drive capability into the post-fader load
  (4 AUX-post gangs + pan + future post-fader output) is well
  within NE5532's specified 600 Ω rating.
- **680 Ω inside the loop** (Self's "zero-impedance output" pattern,
  c.f. Fig. 22.5c): R_FB closes back to the FB node, not to the
  opamp output pin. At audio frequencies, feedback pulls the FB-node
  impedance to near zero; at HF, where loop gain falls, the 680 Ω
  isolates the opamp output pin from capacitive loading on the
  connector / 220 µF and limits short-circuit current. Single
  resistor, two functions.
- **C_FB = 100 pF NPO/C0G** in parallel with R_FB: defines the HF
  pole at ≈ 339 kHz, ~one decade above audio. Three combined
  functions: (1) limits HF gain above audio to attenuate ultrasonic
  content; (2) provides preventive stability margin against parasitic
  capacitance at the −input and capacitive loading on the connector;
  (3) rejects RF residue. Coherent with C_FB = 220 pF on the active
  pan stage in Block 5 (same target HF pole frequency, scaled by
  R_FB).
- **Single dual-gang pot per AUX (one knob = one pre + one post
  send)** rather than 4+4 separate pots. Halves AUX knob count, at
  the cost of forcing the same level shape on pre and post — usually
  what one wants anyway.
- **CUE pot wired with both gangs receiving the pre-fader signal
  identically**: makes a one-knob send to a stereo CUE bus from a
  mono channel, coherent with the "send centered on the stereo
  bus" semantics. Topologically just a duplicated AUX-pre.

#### Open issues for Block 4

- **C_bp** (wiper DC block, bipolar): value TBD.
- **R_bias** (wiper to AGND after C_bp): value TBD. Together with
  C_bp these set the LF rolloff into the post-fader amp's +input
  and define the bias condition of the wiper at startup.
- **Polarity of the 220 µF output DC block**: depends on DC at the
  next stage on the channel PCB (the AUX-post gang tops and the
  pan top). To be set when measured on rev 1.
- **AUX dual-gang pot value** (× 4) and **AUX bus summing resistor
  values** (× 8: 4 pre + 4 post). To be calculated together with
  AUX master summing topology (§05).
- **CUE dual-gang pot value** (× 1) and **CUE bus summing resistor
  values** (× 2: L, R). To be calculated together with CUE master
  summing topology (§06).
- **Fader part / taper / law** — not specified.
- **3-pin connector type / cable** (twisted pair shielded vs flat):
  TBD.

---

### Block 5 — Active pan (FINALIZED)

**Status:** finalized

#### Topology chosen

*Pan pot:*

- **Dual-gang 10 kΩ LIN, center-detent preferred.** Reverse-wired
  between the two gangs so that at one extreme of rotation, one
  wiper sees the input signal while the other sees AGND.
- Top / bottom of each gang to POST-FADER signal / AGND
  (orientations opposite between L gang and R gang).
- Wiper of each gang feeds the +input of one half of an NE5532.

*Active pan stage* (per side, one half-NE5532 per side, both halves
of one NE5532 used for L and R):

Self's active panpot (Fig. 22.12, *Small Signal Audio Design*):
the law-bend resistor is driven from the opamp output rather than
from a fixed voltage, forming a negative-impedance-converter that
shapes the law toward sin/sin² compromise and improves offness
from ≈ 65 dB (passive) to ≈ 90 dB (active).

Per opamp half, three resistors and one capacitor:

- **R_LAW = 3.3 kΩ** — opamp output → non-inverting input. The wiper
  also connects to this same node (i.e. R_LAW and the wiper meet at
  the +input).
- **R_FB = 2.2 kΩ** — opamp output → inverting input. Self canonical.
- **R_G = 10 kΩ** — inverting input → AGND.
- **C_FB = 220 pF NPO/C0G** in parallel with R_FB. HF pole at
  ≈ 329 kHz.

The "non-inverting amp gain" alone (ignoring the law-bend loop) is
1 + R_FB/R_G = 1.22 → **+1.73 dB**.

*Becomes-stereo point:*

The two opamp output pins are the post-pan L and R signals. **The
channel becomes stereo at these two pins** — this is the canonical
"becomes stereo" point for the mono channel.

*Output:*

Post-pan L and R feed Block 6 (rotary routing) + AFL switch +
Post-Fader Output. No DC block at the pan output: NE5532 V_os ≤
0.5 mV typical, and the bias current through R_FB / R_G produces a
small additional DC offset that downstream summers / receivers
either absorb (virtual-earth nodes) or block (AC-coupled inputs).

#### Active devices

- **NE5532 × 1 per channel** (dual SOIC; both halves used, one for
  L, one for R). Per global default in `00-conventions.md`.

#### Key passive values

- R_LAW = 3.3 kΩ × 2 (one per side) = 2 per channel.
- **R_FB = 2.2 kΩ × 2** = 2 per channel. Self canonical.
- R_G = 10 kΩ × 2 = 2 per channel.
- **C_FB = 220 pF NPO/C0G × 2** per channel. HF pole at ≈ 329 kHz.
- Pan pot: dual-gang 10 kΩ LIN, center-detent preferred.

#### Design targets / expected performance

(With Self's canonical values: pot = 10 kΩ, R_LAW = 3.3 kΩ,
R_FB = 2.2 kΩ, R_G = 10 kΩ.)

- Hard-pan output level: **+1.73 dB** (relative to POST-FADER, on
  the active side).
- Center output level: **−2.77 dB** (relative to POST-FADER, each
  side).
- **Center dip: ≈ 4.5 dB** — Self's canonical sin/sin² compromise
  law. Psychoacoustically uniform perceived level across the pan
  travel.
- HF pole: ≈ 329 kHz. Audio-band response flat to within −0.02 dB
  at 20 kHz.
- Offness when panned hard one side: limited by pot end-of-track
  resistance, ≈ 90 dB on the inactive side (active law-bending
  improvement over the ≈ 65 dB of a passive pan).

#### Decisions and tradeoffs

- **Active pan over passive law-bending.** Self's pattern: cleaner
  pan law and significantly better offness at the cost of one dual
  opamp per channel.
- **Self canonical values (R_FB = 2.2 kΩ, R_G = 10 kΩ, R_LAW = 3.3 kΩ,
  pot = 10 kΩ LIN).** The four values are tuned together to land on
  the sin/sin² compromise law with ≈ −4.5 dB center dip — the
  psychoacoustic compromise between constant-amplitude (−6 dB at
  center, hole-in-the-middle) and constant-power (−3 dB at center,
  bump-in-the-middle). Increasing R_FB (e.g. to 4.7 kΩ) would
  flatten the dip toward ≈ 2 dB and produce a "soft center" voicing
  with a perceptible level jump from hard-panned to center; we
  follow Self.
- **C_FB = 220 pF NPO/C0G**: HF pole at ≈ 329 kHz. Three combined
  functions: (1) limits HF gain above audio; (2) gives preventive
  stability margin in the law-bend positive-feedback loop (R_LAW
  closes from the opamp output back to the +input — limiting HF
  forward gain caps the loop gain before parasitic phase shifts can
  cause trouble); (3) rejects RF residue at the wiper, which is a
  high-Z node with front-panel cabling. Coherent with C_FB = 100 pF
  on the post-fader amp in Block 4 (same target HF pole frequency,
  scaled by R_FB). NPO/C0G dielectric for low voltage coefficient
  and low loss.
- **NE5532**: per global default in `00-conventions.md`. The +input
  sees the wiper (variable Z, 0 to ~2.5 kΩ depending on pan position)
  in parallel with R_LAW = 3.3 kΩ from the output. With NE5532 I_B
  ~ 200 nA, position-dependent DC offset at the +input is at most
  ~500 µV across the pan travel — negligible and inaudible at any
  practical pan-knob speed. Block 5 is identified as a candidate
  for selective opamp upgrade (OPA1642 JFET, or OPA1656 for noise)
  at the budget-review stage; the topology and all passive values
  are unchanged across this upgrade — see `00-conventions.md` and
  `10-open-tbd.md`.
- **Center-detent pot preferred**: gives the engineer a tactile
  reference for "hard center" without looking. Optional.
- **No DC block at pan output**: NE5532 output offset is small, and
  downstream destinations are either virtual-earth bus summers
  (DC-tolerant) or AC-coupled inputs. Saves capacitors and avoids
  inserting LF poles.

#### Open issues for Block 5

- **Pan pot exact part** — dual-gang 10 kΩ LIN center-detent, model
  TBD.

---

### Block 6 — Post-pan routing rotary (PARTIAL — values TBD)

**Status:** in-progress — topology defined, bus summing resistor
values to be calculated together with §07 (Main) and §04 (Groups).

#### Topology chosen

*Rotary switch (§2.9 (a)):*

- **2-gang × 4-position rotary**, mechanical, front-panel.
- Centrals (poles) of gang L and gang R are fed by the post-pan L
  and R signals from Block 5.
- Each of the 4 positions on each gang connects through a bus
  summing resistor to one of the four destination buses
  (Main / G1 / G2 / G3), respectively L or R sub-bus.
- 4 positions × 2 gangs = **8 bus summing resistors per channel**
  for this stage.
- One destination active at a time per channel; the inactive
  positions leave the corresponding bus summing resistor floating
  on the channel side (no back-grounding).

#### Active devices

None on this stage.

#### Key passive values

- 8 × bus summing resistors per channel: TBD. To be calculated
  together with §07 (Main summer) and §04 (group summers).
- Rotary switch: 2-gang, 4-position, mechanical, front-panel; part
  TBD.

#### Decisions and tradeoffs

- **Rotary over individual mechanical push-switches per
  destination**: simpler front panel, only one position active by
  construction, saves panel space at the cost of being unable to
  send a single channel to multiple stereo destinations
  simultaneously. Acceptable given the modest group count (3) and
  the operator's ability to use AUX sends and groups together for
  multi-destination workflows.
- **Open inactive positions, not back-grounded**: with the post-pan
  L/R NE5532 outputs sourcing each destination through its own
  bus summing resistor, the load presented to the pan stage varies
  with rotary position by ≈ 0 (one resistor at a time, all
  approximately the same value). No need for back-grounding;
  saves 8 resistor positions per channel on the rotary.

#### Open issues for Block 6

- **Bus summing resistor values** (8 per channel × 24 channels =
  192 resistors total, plus contributions from AUX returns and
  groups). To be solved together with §04 and §07.
- **Rotary switch part selection** (2-gang, 4-position, mechanical,
  make-before-break vs break-before-make): TBD. Probably
  break-before-make to avoid momentary cross-routing during
  position change.

---

### Block 7 — AFL switch (post-pan stereo tap) (FINALIZED)

**Status:** finalized — topology and relay wiring fixed; AFL bus
summing resistor values deferred to §08.

#### Topology chosen

*AFL tap (§2.9 (b)):*

- Tap directly from each post-pan opamp output (Block 5): one tap
  for L, one for R.
- Each tap feeds a **bus summing resistor** (value TBD — see §08)
  in series, whose far end connects to COM of the respective
  contact set on the AFL relay.
- **Contact set 1** carries L; **contact set 2** carries R. Both
  are mechanically ganged on the same coil (one AGQ210A03, DPDT
  1-coil latching) — L and R switch perfectly synchronously.
- **NC contacts → AGND**: in the RESET state (AFL off), the far
  end of each summing resistor is terminated to AGND. The post-pan
  opamp output always sees a constant resistive load (the summing
  resistor alone) regardless of AFL state — no impedance step on
  switching, no click.
- **NO contacts → AFL bus**: in the SET state (AFL on), the far
  end of each summing resistor connects to the AFL Left / AFL Right
  bus respectively.

Boot-up default: RESET (AFL off, NC contacts on AGND). Per the
console-wide firmware boot-init contract.

#### Active devices

- **AGQ210A03 × 1 per channel** (DPDT 2 form C, 1-coil latching
  signal relay). Contact set 1 = L; contact set 2 = R. Per
  `00-conventions.md` "Standard signal relay".

#### Key passive values

- AFL bus summing resistors: × 2 per channel (L and R). Value TBD
  — to be calculated together with §08 AFL summer design.

#### Design targets / expected performance

- Constant resistive load on post-pan L/R opamp output in both AFL
  states: R_load = summing resistor value (terminated to AGND or
  feeding AFL bus — both look like a resistive load to the opamp).
- Off-isolation: open-contact isolation > 80 dB at 1 MHz per
  datasheet, effectively unbounded at audio.

#### Decisions and tradeoffs

- **NC → AGND (terminated, not floating)**: gives constant
  resistive loading on the post-pan output in both AFL on and off
  states. Avoids any thump or level shift when switching. The
  summing resistor dissipates a small signal power to AGND at all
  times in AFL-off state — negligible at audio signal levels.
- **Tap directly from the post-pan opamp output** (Block 5), no
  buffer. NE5532 V_os is small enough that no DC block is needed
  before the AFL bus summer. The summing resistor serves both as
  AFL bus contribution weight and as switch source impedance.
- **Summing resistor value deferred to §08**: AFL bus summing
  resistors must be designed together with the AFL summer /
  monitor section (§08) as a coherent system (source count,
  individual resistor values, and summer opamp gain interact).

#### Open issues for Block 7

- **AFL bus summing resistor value** (× 2 per channel, L and R).
  TBD together with §08 AFL summer design.

---

### Block 8 — OUT-PRE/POST switch + switchable Channel Output (IN-PROGRESS)

**Status:** in-progress — signal flow and relay topology fixed;
LED colors assigned (all orange); cold dummy network details TBD.

#### Topology chosen

*Pre-mute signal tap (on channel PCB):*

- A **75 Ω** resistor taps the pre-MUTE node — the HPF/INSERT bypass
  relay COM2 output — which is the same node that feeds the meter
  buffer (Block 3) and the MUTE relay COM1. This is a branch tap, not
  in series with the main path. The far end of this 75 Ω is one input
  to the OUT-PRE/POST switch.

*Post-fader signal tap (on channel PCB):*

- A **75 Ω** resistor taps the POST-FADER node (after the
  post-fader amp, before pan). Branch tap. Far end = other input
  to the OUT-PRE/POST switch.

*OUT-PRE/POST switch (on channel PCB, front-panel):*

- **DPDT mechanical switch, front-panel.** Pattern A per
  `00-conventions.md`.
- Section 1 (signal): common feeds pin 1 of the 2-pin connector
  (below). Throws select between the pre-mute 75 Ω output (PRE)
  and the post-fader 75 Ω output (POST).
- Section 2 (indicator): COM connected to the NO throw of
  DIR/PROC button Section 2 (powered only when PROCESSED is
  selected). Throws: NC = LED-PRE (orange), NO = LED-POST
  (orange). Both LEDs are dark when DIRECT is selected; only
  the appropriate one lights when the channel output is in
  PROCESSED mode.

*2-pin connector — channel PCB → input PCB:*

- **Pin 1 (hot)**: the signal selected by the OUT-PRE/POST
  switch (already through the chosen 75 Ω build-out).
- **Pin 2 (cold dummy)**: a dedicated **75 Ω to AGND** only — no
  47 µF ‖ 47 kΩ completion. The two source paths have incompatible
  upstream DC-block conditions (PRE path: 47 µF blocks with 47 kΩ
  pull-down; POST path: 220 µF output block from fader PCB with no
  pull-down at the tap point), so a single matched cold dummy
  network cannot suit both positions. A simple 75 Ω to AGND gives
  frequency-independent impedance balance over this short internal
  run and is the correct compromise.

*DIR/PROC button (on channel PCB, front-panel):*

- **Latching DPDT pushbutton**, named "DIRECT / PROCESSED output".
- **Section 1**: routes to the digital/driver board (same path as
  all other front-panel switches). On the digital board the latched
  contact state is used to command the Channel Output SELECT relay
  coil. **TBD**: whether sec. 1 feeds an MCU GPIO (firmware-
  mediated, Pattern B) or connects directly to the bipolar coil
  driver bypassing the MCU. The latching switch makes the hardware-
  bypass path viable: the driver can read the static contact state
  and generate SET/RESET pulses without toggle logic or firmware
  involvement. Decision deferred to the relay driver IC / architecture
  choice (see `10-open-tbd.md`).
- **Section 2**: COM = +3.3 V (DGND return). NC throw =
  LED-DIRECT (orange). NO throw = COM of OUT-PRE/POST switch
  Section 2. This chains the two switches so that LED-PRE and
  LED-POST are powered only when PROCESSED is selected. Three
  mutually exclusive LED states, zero MCU GPIO:
    - DIRECT selected (NC): LED-DIRECT ON; LED-PRE and LED-POST dark.
    - PROCESSED + PRE: LED-DIRECT off; LED-PRE ON; LED-POST off.
    - PROCESSED + POST: LED-DIRECT off; LED-PRE off; LED-POST ON.

*Channel Output SELECT relay (on input PCB):*

- **AGQ210A03** (DPDT 2 form C, 1-coil latching signal relay, per
  `00-conventions.md`). See also Block 1 (Channel Output section) for
  the PCB context.
- **Contact set 1 (hot line):** COM → Channel Output EMI filter tip
  (→ TRS tip). NC = 75 Ω build-out on Input A hot buffer (existing
  path). NO = pin 1 of 2-pin connector (channel PRE/POST signal).
- **Contact set 2 (cold line):** COM → Channel Output EMI filter ring
  (→ TRS ring). NC = 75 Ω build-out on Input A cold buffer
  (existing path). NO = pin 2 of 2-pin connector (cold dummy from
  channel PCB).
- **RESET state (Input A — default):** Channel Output = full-
  differential from Input A buffers through their matched 75 Ω
  build-out resistors. Original behavior, unchanged.
- **SET state (Channel signal):** Channel Output = impedance-balanced;
  hot = selected PRE or POST signal (already through 75 Ω); cold =
  75 Ω-to-AGND cold dummy from channel PCB.
- In both states, signal passes through the standard T-balanced
  double-pi EMI filter on the Channel Output TRS jack.

#### Active devices

- **AGQ210A03 × 1 per channel** (DPDT 2 form C, 1-coil latching
  signal relay): Channel Output SELECT. Per `00-conventions.md`
  "Standard signal relay". Sits on the input PCB.

#### Key passive values

- Pre-mute 75 Ω tap: **75 Ω** (0603 1 %), on channel PCB.
- Post-fader 75 Ω tap: **75 Ω** (0603 1 %), on channel PCB.
- Cold dummy 75 Ω: **75 Ω** (0603 1 %), on channel PCB.
- Cold dummy bypass / load network (47 µF ‖ 47 kΩ): TBD.
- OUT-PRE/POST switch LED current-limit resistors (PRE + POST): TBD.
- DIR/PROC button DIRECT LED current-limit resistor: TBD.

#### Design targets / expected performance

- Channel Output in Input-A state: full-differential, same
  specification as Block 1 Channel Output.
- Channel Output in Channel-signal state: impedance-balanced output.
  Source impedance looking into tip = 75 Ω (matched to cold dummy
  75 Ω to AGND). Downstream CMR limited by impedance balance,
  not by differential drive.

#### Decisions and tradeoffs

- **Channel Output jack as multifunction output**: combines the
  original full-differential Input A tracking output with a
  channel-signal output (pre-mute or post-fader). Eliminates the
  need for a separate rear-panel "Post-Fader Output" jack
  (original §2.9 (e) concept), reducing jack and connector count.
- **OUT-PRE/POST as a mechanical switch (not firmware-
  controlled)**: set directly by the operator, appropriate for
  a per-session configuration choice (recording pre vs post fader).
  No firmware needed for this selection.
- **Channel Output SELECT as a relay (AGQ210A03, firmware-controlled)**:
  allows remote switching of the Channel Output source (e.g. for a
  global "engage all channel sends" command, or DAW integration),
  consistent with the console-wide relay-for-firmware-control
  approach.
- **75 Ω build-outs on both PRE and POST tap paths**: provides the
  correct source impedance for the Channel Output EMI filter in the
  Channel-signal state (same rationale as Input A build-out —
  see Block 1). Both taps use 75 Ω to stay consistent with the
  standard impedance-balanced output convention.
- **Cold dummy as plain 75 Ω to AGND (no 47 µF ‖ 47 kΩ completion)**:
  the two source paths have incompatible upstream conditions. The
  PRE path has 47 µF DC blocks with 47 kΩ pull-down upstream; the
  POST path exits the fader PCB through a 220 µF output block with
  no pull-down at the tap point. A single completion network cannot
  properly match both positions. Plain 75 Ω to AGND gives frequency-
  independent impedance balance over this short internal PCB-to-PCB
  run — the correct practical compromise.

#### Open issues for Block 8

- **LED-PRE, LED-POST, LED-DIRECT colors**: all orange. Resolved.
- **Channel Output SELECT relay boot state**: RESET (Input A /
  direct default) is the expected choice; to be confirmed and
  recorded in the firmware boot-init spec.

---

### Block 9 — HPF / INSERT chain bypass relay (IN-PROGRESS)

**Status:** in-progress — relay wiring and front-panel hardware
established; logical mode cycling and boot state TBD.

#### Topology chosen

Standard **AGQ210A03** DPDT 1-coil latching signal relay per
`00-conventions.md`. Contact wiring per §2.3.1:

| Contact | Connection |
|---|---|
| COM1 | SOURCE relay output |
| NC1 | Hard-wired to NC2 |
| NC2 | Hard-wired to NC1 |
| COM2 | Pre-MUTE node (meter buffer + PFL tap + MUTE relay COM1) |
| NO1 | HPF switch Section 1 input (chain entry) |
| NO2 | Insert Return receiver output, post-C38 (chain exit) |

- **RESET (NC active):** COM1 → NC1 ↔ NC2 → COM2. HPF / INSERT
  chain bypassed.
- **SET (NO active):** COM1 → NO1 → [HPF + INSERT chain] → NO2 →
  COM2. Chain in signal path.

Front-panel control:

- **Momentary pushbutton**, single contact, MCU GPIO input.
- **Three separate orange LEDs**, each driven by an individual MCU
  GPIO output: FOLLOW PATH (center), FOLLOW A, FOLLOW B — per the
  mode table in §2.3.1.

#### Active devices

- **AGQ210A03 × 1 per channel** (DPDT 2 form C, 1-coil latching
  signal relay). Per `00-conventions.md` "Standard signal relay".

#### Key passive values

- FX-FOLLOW LED current-limit resistors (× 3 per channel):
  TBD (depends on chosen LED Vf and brightness target).
- Coil drive: bipolar pulse from +3.3 V per `00-conventions.md`
  "Standard signal relay". Driver IC TBD.

#### Open issues for Block 9

- **Boot state**: RESET (chain bypassed by default) or SET (chain
  in path by default) — TBD. See `10-open-tbd.md`.
- **Mode cycling logic and SOURCE synchronization**:
  firmware decision — TBD. See `10-open-tbd.md`.
- **Front-panel button part** (momentary, single contact, no
  integrated LED): TBD.

---

### Block 10 — Dual meter buffers (FINALIZED)

**Status:** finalized

#### Topology chosen

*Active meter buffer (TL072 half 1):*

- Input: pre-MUTE node (HPF/INSERT bypass relay COM2). DC-free in both
  relay states per Block 3. No DC block at the TL072 input.
- Bias return: 47 kΩ to AGND already present at the pre-MUTE node
  (from Block 2 R22 / Block 1 post-receiver DC-block network, depending
  on bypass relay state). TL072 JFET input bias current ≈ pA —
  DC offset at input ≈ 0. No additional bias resistor needed.
- Configuration: unity-gain voltage follower (inverting input
  connected directly to output).
- Output: 75 Ω build-out → pin 1 of 3-pin connector to meter bridge.

*Inactive meter buffer (TL072 half 2):*

- Input: SOURCE relay contact set 2, COM2 output. Set 2 is
  wired complementary to set 1 (see Block 1): NC2 = Receiver B
  (post-DC-block); NO2 = Receiver A (post-DC-block). In RESET state
  (A active), COM2 delivers Receiver B; in SET state (B active), COM2
  delivers Receiver A. Source selection is performed by the relay
  itself — no additional electronic switch.
- DC-free: 47 µF DC blocks in Block 1 are upstream of both receiver
  outputs. No DC block at the TL072 input.
- Bias return: 47 kΩ pull-down at each receiver output (Block 1
  post-DC-block networks). TL072 JFET input bias current ≈ pA →
  DC offset ≈ 0. No additional bias resistor needed.
- Configuration: unity-gain voltage follower (inverting input
  connected directly to output).
- Output: 75 Ω build-out → pin 2 of 3-pin connector to meter bridge.

*3-pin connector — channel PCB → meter bridge PCB:*

- Pin 1: active meter signal (post-75 Ω). Full brightness.
- Pin 2: inactive meter signal (post-75 Ω). Dimmed on meter bridge.
- Pin 3: AGND.

The meter bridge PCB carries a full AGND pour (no TRS jacks — Muncy
Pin 1 rule does not apply). A separate DGND pour serves the LED driver
ICs. Dimming of the inactive bargraph is a meter bridge design decision
— the channel PCB delivers both signals at full amplitude.

#### Active devices

- **TL072** × 1 per channel (dual SOIC, JFET input): both halves used.
  Half 1 = active meter buffer (pre-MUTE tap); half 2 = inactive meter
  buffer (SOURCE relay contact set 2 output).

#### Key passive values

- Meter buffer build-out: **75 Ω × 2** (0603 1 %), one per TL072
  half output.

#### Design targets / expected performance

- Both buffers: unity gain, DC–audio band. Output drives ≈ 100 pF
  cable capacitance via 75 Ω build-out without ringing.
- DC offset at both TL072 inputs: ≈ 0 (JFET bias current in pA range).

#### Decisions and tradeoffs

- **SOURCE relay contact set 2 for inactive meter switching**
  (no additional electronic switch): contact set 2, wired with NC/NO
  complementary to set 1, delivers the inactive receiver at all times
  with relay-contact quality (Ron ≤ 100 mΩ, isolation > 80 dB at
  1 MHz). Eliminates one IC per channel and all associated passives.
- **TL072 over NE5532**: ~3× lower quiescent current (~2.5 mA/package
  vs ~8 mA) and JFET inputs (bias current ≈ pA vs ~200 nA). For a
  meter buffer — not in the critical audio chain, destination is a
  rectifier — TL072 is preferable: lower power and zero DC offset at
  the input. Higher voltage noise (18 nV/√Hz vs 5 nV/√Hz) is
  irrelevant for this application.
- **No bias resistors at TL072 inputs**: JFET inputs draw pA; upstream
  47 kΩ pull-downs provide the return path. DC offset ≈ 0.
- **3-pin connector (vs two separate 2-pin connectors)**: saves one
  connector per channel; shared AGND adequate for this short internal
  run to the meter bridge.
- **Dimming on meter bridge, not on channel PCB**: channel PCB delivers
  both signals at full amplitude; meter bridge applies different drive
  conditions per input. Keeps channel PCB simple.

#### Open issues for Block 10

- **Connector type** for 3-pin to meter bridge PCB: TBD.
- **Inactive bargraph dimming ratio**: LED drive threshold or current
  ratio on meter bridge PCB — TBD when meter bridge is designed.

---

## 2.11 Front-panel control buttons

Per mono channel there are **10 pushbuttons** in three categories:

**Momentary with integrated LED (3) — physically on the fader PCB:**
ACTIVE (orange), SOLO (red), REC (red). LED is inside the
button body; not listed separately in the LED inventory. Connection
from fader PCB to digital logic PCB: TBD.

**Momentary without integrated LED (2) — on channel/input PCB:**
SOURCE (§2.2) and FX-FOLLOW (§2.3.1).

**Latching DPDT (5) — on channel/input PCB:**
HPF (§2.3.2), INSERT (§2.3.3), PFL (§2.5.2), Output PRE/POST
(§2.9 (e)), DIR/PROC (§2.9 (e) / Block 8). For
each: section 1 carries the signal or GPIO-to-MCU control line;
section 2 drives an indicator LED.

### ACTIVE (orange LED)

- Button press → firmware toggles the **MUTE relay** (AGQ210A03,
  §2.6) between ACTIVE (SET) and MUTED (RESET).
- Orange LED on = channel ACTIVE; off = MUTED. Driven by MCU GPIO.
- Boot default: LED off, relay RESET (channel muted).

### SOLO (red LED)

- Button press → firmware:
  1. Sets the **AFL relay** (AGQ210A03, §2.9 (b)) of this channel
     to SET — post-pan L/R joins the AFL bus.
  2. Optionally (SIP mode): drives the **MUTE relay** of every
     other channel to RESET (muted), leaving this channel's MUTE
     relay in its current ACTIVE state.
- Red LED on = this channel soloed. Driven by MCU GPIO.
- Un-pressing SOLO reverses both actions: AFL relay to RESET;
  other channels' MUTE relays restored to their pre-solo state.
- AFL-only vs. SIP mode and multi-SOLO priority: firmware
  decisions, TBD.

### REC (red LED)

- Button press → firmware toggles the REC state of this channel.
- No audio relay involved. Firmware signals armed/unarmed state
  toward the DAW via MIDI (exact protocol TBD).
- Red LED on = channel armed for recording. Driven by MCU GPIO.
- Boot default: LED off (unarmed).

### HPF / INSERT BYPASS (three separate orange LEDs)

- Button press → firmware cycles the HPF/INSERT bypass relay
  (AGQ210A03, §2.3.1) through three modes: FOLLOW PATH → FOLLOW A
  → FOLLOW B → FOLLOW PATH → …
- Three separate orange LEDs (not integrated in the button), each
  driven by a dedicated MCU GPIO output. Exactly one LED is on at
  all times, indicating the current mode.
- Boot default and mode cycling logic: TBD — see `10-open-tbd.md`
  and Block 9 open issues.

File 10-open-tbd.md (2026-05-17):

# 10 — Open / TBD

Items deliberately unresolved at this stage. As they get resolved,
remove them from here and record the decision in the relevant
section's Implementation details.

---

## Block-specific open issues

### From mono channel Block 1 (input + receiver)

- **Phase-lead compensation on balanced receivers** — Jung/Kester
  Fig. 6-26 describes an optional R-C trim network to improve HF CMR
  by ≈ 30 dB at 10 kHz. Not implemented in first rev. Footprints will
  be present on PCB; populate in rev 2 if measured CMR at 10 kHz is
  insufficient.
- **Receiver matched-resistor part selection** — 0.1 % thin-film
  recommended; exact part TBD (candidates: Susumu RR0816P, Vishay
  MCT0603, etc.).
- **Bipolar electrolytic brand / series** for signal-path coupling
  (candidates: Nichicon Muse ES, Panasonic SU, Elna Silmic bipolar).
- **DPDT mechanical switch** part selection for HPF / INSERT.
  (SOURCE is no longer a mechanical DPDT — it is a
  momentary pushbutton + firmware-driven AGQ210A03 latching relay
  per `00-conventions.md`; the front-panel pushbutton part is
  itself TBD.)
- **Ferrite chip part selection** — 330 Ω @ 100 MHz, many
  equivalents; choose by current rating and package.

### From mono channel Block 2 (HPF + Insert)

- **HPF voicing** — topology copied from another mixer produces
  3rd-order rolloff with a +5 dB resonant peak around 80 Hz (Q ≈ 3.46
  on the Sallen-Key stage). To revisit: confirm as intentional voicing
  or rebalance toward Butterworth (Q ≈ 0.7, R24 → ~31 kΩ). See
  `02-mono-channel.md` §2.10 Block 2.
- **Send cold dummy network — low-frequency CMR**: the 47 µF dummy
  cap introduces a tip vs ring impedance mismatch below ~100 Hz,
  degrading CMR exactly where mains hum lives. Default pattern in
  `00-conventions.md` reflects current choice; revise (larger dummy
  cap or alternative topology) if measured hum rejection on Insert is
  insufficient.
- **HPF film cap dielectric** (PPS / PET / PP / NPO depending on
  physical size at 220 nF) — TBD.
- **HPF switch and INSERT switch part selection** (DPDT, front-panel,
  current rating adequate for LED section).
- **INSERT blue LED Vf headroom on +3.3 V rail.** Standard blue
  LED Vf is 3.0–3.4 V, leaving very little margin across the
  current-limit resistor on a +3.3 V supply. Either source a
  low-Vf blue (≈ 2.7 V) at the chosen brightness, or revisit the
  LED color choice for the INSERT indicator. To resolve when
  selecting the actual LED parts.

### From mono channel Block 3 (meter buffer + PFL + MUTE)

- **Channels per input PCB** (likely 4 or 6) — TBD. Note: this is
  now decoupled from the relay-coil-drive routing question: per
  `00-conventions.md` ("PCB partitioning — stackable two-board
  pattern"), each relay's coil exits the audio PCB through its
  own 3-pin connector to a lower stackable digital PCB, so the
  number of channels per input PCB no longer dictates a
  per-channel-mute connector layout. The **fader PCB** partitioning
  is settled (2 channels per fader PCB — see Block 4); the input
  PCB partitioning remains independent and TBD.
- **Other PFL sources feeding PFL DETECT**: AUX masters (`05`),
  AUX returns (`03`), and groups (`04`) all carry PFL controls. Do
  they all need to feed the PFL DETECT logical bus to drive the
  firmware source-select? — TBD. Probably yes for coherent
  monitor-switching semantics, but to be confirmed when those
  sections are detailed.
- **PFL signal diode** — 1N4148-class, exact part TBD.
- **PFL LED current-limit resistor value** — depends on chosen LED
  Vf and brightness target.

### From mono channel Block 4 (pre-fader node + fader PCB + post-fader amp + AUX/CUE sends)

- **C_bp** (bipolar DC block at the fader wiper, on the fader PCB):
  value TBD.
- **R_bias** (wiper to AGND after C_bp): value TBD. Together with
  C_bp these set the LF rolloff into the post-fader amp's +input
  and define the wiper bias condition at startup. With NE5532
  (I_B ~ 200 nA) the order-of-magnitude target is 47 kΩ → ~9 mV
  DC at the +input, absorbed by the 220 µF output DC block.
- **Polarity of the 220 µF output DC block** at the fader PCB
  output: depends on DC at the next stage (AUX-post gang tops and
  pan top on the channel PCB). To be set when measured on rev 1.
- **AUX dual-gang pot value** (× 4) and **AUX bus summing resistor
  values** (8 total per channel: 4 pre + 4 post). To be calculated
  together with the AUX master summing topology (`05`).
- **CUE dual-gang pot value** (× 1) and **CUE bus summing resistor
  values** (× 2: L + R per channel). To be calculated together with
  the CUE master summing topology (`06`).
- **Fader part / taper / law** — not specified.
- **3-pin connector type / cable** between channel PCB and fader
  PCB (twisted pair shielded vs flat ribbon): TBD.

### From mono channel Block 5 (active pan)

- **Pan pot exact part** — dual-gang 10 kΩ LIN center-detent
  preferred; model TBD.

### From mono channel Block 6 (post-pan routing rotary)

- **Bus summing resistor values** (8 per channel × 24 channels =
  192 resistors from this stage alone, plus contributions from AUX
  returns and groups via their own routing). To be solved together
  with `04` (group summers) and `07` (Main summer) — they form one
  coherent system.
- **Rotary switch part selection** — 2-gang, 4-position, mechanical,
  front-panel: TBD.
- **Make-before-break vs break-before-make** — probably
  break-before-make to avoid momentary cross-routing during a
  position change.

### Mono channel — AFL switch (post-pan, stereo) — FINALIZED (summing values TBD)

`02-mono-channel.md` §2.9 (b) and Block 7. Topology now fully fixed:
tap at the post-pan opamp output (Block 5); per-side bus summing
resistor → COM of AGQ210A03; NC contacts to AGND (constant termination
when AFL off, click-free); NO contacts to AFL Left / AFL Right bus.

Still to be decided:

- **AFL bus summing resistor value** (× 2 per channel, L and R):
  TBD together with §08 AFL summer design (source count, individual
  resistors, and summer opamp gain form one coherent system).

### From mono channel Block 9 (HPF/INSERT chain bypass relay) — in-progress

- **Boot state**: RESET (chain bypassed at power-up) or SET (chain
  always active at power-up). To decide with the firmware boot-init
  spec. RESET is the "safe audio path" default (bypass = no
  processing); SET is the "always insert" default.
- **Mode cycling logic**: the button cycles FOLLOW PATH → FOLLOW A →
  FOLLOW B → FOLLOW PATH. Firmware must track current mode and
  synchronize relay state to the SOURCE relay state in FOLLOW A
  and FOLLOW B modes (i.e., respond to SOURCE changes even
  without a button press). Details TBD.
- **Front-panel button part** (momentary, single contact, no integrated
  LED): TBD.

---

### Mono channel — Block 8 (OUT-PRE/POST switch + switchable Direct Out) — in-progress

`02-mono-channel.md` §2.9 (e) and Block 8. The standalone
Post-Fader Output dedicated jack (original §2.9 (e)) is superseded:
channel signal is now routed to the input PCB via a 2-pin connector,
and the Direct Out TRS jack is made switchable via the DIRECT OUT
SELECT relay. Topology is fixed; remaining open items:

- **OUT-PRE/POST and DIR/PROC LED colors**: LED-PRE, LED-POST,
  LED-DIRECT — all orange. Resolved.
- **DIR/PROC sec. 1 — MCU or direct-to-driver**: front-panel
  element confirmed as latching DPDT pushbutton. Sec. 1 routes to
  the digital/driver board like all other switches. TBD: whether
  sec. 1 feeds an MCU GPIO (firmware-mediated, Pattern B) or
  connects directly to the bipolar coil driver, bypassing the MCU.
  The latching switch makes the hardware-bypass path viable without
  toggle logic. Decision deferred to the relay driver IC /
  architecture choice (see "Standard signal relay" open issue).
- **DIRECT OUT SELECT relay boot state**: RESET (Input A default)
  is the expected choice; to be confirmed with the firmware
  boot-init spec.

---

## Conceptual / design-phase open issues

- **Standard signal relay — driver IC, partitioning, supply,
  protection.** The standard electronic switch in CONSOLE is the
  **AGQ210A03** (1-coil latching, 3 V coil, per
  `00-conventions.md`). Approximately 112 relays total across the
  console (24 mono channels × 4 positions — SOURCE, MUTE,
  AFL, DIRECT OUT SELECT — + 4 AUX returns × 2 + 3 groups × 2 +
  2 in master monitor).
  Open items (relay count updated: 136 total — 24 mono channels × 5
  positions SOURCE, MUTE, AFL, DIRECT OUT SELECT, FX-FOLLOW +
  4 AUX returns × 2 + 3 groups × 2 + 2 monitor):
  - **Coil driver IC**: bipolar / half-H-bridge per relay
    (set-pulse and reset-pulse drive). Candidates: Toshiba
    TBD62783A high-side + TBD62083A low-side pair sharing 8
    channels, dedicated octal latching-relay drivers
    (e.g. MAX4820 / MAX4821), per-relay discrete NPN+PNP pair, or
    purpose-built relay-driver SoCs. Choice and protection
    network (freewheeling diodes / suppression for the bipolar
    drive) decided together.
  - **Coil supply rail**: settled — direct drive from the +3.3 V
    logic rail (the 3 V coil tolerates +3.3 V transiently, within
    150 % max allowable; the pulse-only duty cycle makes the small
    overdrive thermally irrelevant). Local bulk on the +3.3 V
    plane sized to absorb pulse-current transients per PCB.
  - **Coil rail bulk capacitance per PCB**: pulse current
    transients up to ~33 mA per relay × N relays simultaneously
    toggled. Firmware staging keeps the worst case manageable;
    bulk cap sized to limit ΔV during a pulse.
  - **Firmware boot-init protocol**: at every cold boot, every
    relay must be driven to its known reset state by an explicit
    pulse. Scheduling and progress reporting to the master-mute
    release logic (see "Master-output hard-mute" below) is part
    of the firmware spec.
  - **Relay coil RF / audible click radiation**: PCB layout to
    keep coil currents tightly looped, away from audio traces.
- **Master-output hard-mute during firmware boot init.** With the
  switch to a latching standard signal relay, the per-position
  fail-safe-by-construction at power-up is gone (a latching relay
  holds whatever state it was last commanded into; transport /
  installation impact may also disturb it). A separate hardware
  mute on the master output stage must hold the room silent until
  firmware finishes initializing all latching relays to their
  designated reset states. Topology of that master mute (relay,
  CMOS analog switch, depletion-mode FET shunt, etc.), its
  release semantics (firmware "ready" handshake), and its boot
  default direction are part of the master-section design, not
  yet started.
- **Selective opamp upgrade — budget-review stage.** Default audio
  opamp is NE5532 per `00-conventions.md`. At the prototype /
  measurement stage, identify positions where NE5532 limitations
  (~200 nA bipolar input bias current, ~5 nV/√Hz noise, BJT
  CM-distortion at high source impedance) measurably impact the
  result. Strongest candidates within the mono channel:
  - **Block 5 active pan** — +input sees a high-Z, position-dependent
    source (wiper of 10 kΩ pot in parallel with R_LAW = 3.3 kΩ from
    the output). Both bias-current offset stability and CM-distortion
    benefit from a JFET / CMOS input.
  - **Block 2 HPF Sallen-Key** — +input swings the full audio signal
    at high Z (62 kΩ to AGND); CM-distortion is the most visible
    penalty of NE5532 here.
  - Less critical but worth review: Block 4 post-fader amp, meter
    buffer.
  Upgrade options: **OPA1642** (JFET, low CM-distortion, drop-in,
  ~negligible bias current) or **OPA1656** (CMOS, lowest noise of the
  three at 1.6 nV/√Hz, drop-in). Topology and all passive values
  (R_FB / R_G / R_LAW / C_FB / etc.) remain unchanged across any of
  these substitutions — only the part marking on the SOIC changes.
- **Monitor-section output destination** — control room? headphones?
  Both? — path ends at the mono/check buttons currently.
- **AFL vs PFL priority** when both are simultaneously active —
  firmware decision.
- **SOLO vs ACTIVE exact semantics** — the electronic switches exist
  in hardware; whether SOLO-in-place mutes non-solo channels, whether
  AFL is latching or destructive to the main mix, etc., are firmware
  choices.
- **Op-amp choices for stages still conceptual**: AUX/CUE/PFL summer
  opamps (master sections `05` `06`), Main summer opamp (`07`),
  AFL/PFL summer opamps (`08`), monitor-section switches, meter-bridge
  active stages. Default per `00-conventions.md` is NE5532 unless a
  specific Block argues otherwise.
- **PSU design** — TBD.
- **Channel physical layout** (which knob sits where) — not
  specified.
- **System-wide grounding scheme** — AGND / DGND / Chassis kept
  separate per-PCB. Joining topology (star point at PSU, ferrite
  bead, direct bond, etc.) not yet decided.

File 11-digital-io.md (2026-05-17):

# 11 — Digital I/O Summary

Running count of every relay, front-panel LED, and digital pushbutton
in the console. **Keep this file in sync with the design**: whenever
a relay, LED, or button is added, removed, or changed in any section
file, update the relevant table here.

Status flags: ✓ = confirmed from finalized blocks or fixed decisions;
~ = estimated from sections still conceptual (numbers firm up as those
sections are implemented).

---

## Relays

All relays are **AGQ210A03** (DPDT 2 form C, 1-coil latching, 3 V coil,
per `00-conventions.md` "Standard signal relay").

| Section | Function | Per unit | Units | Subtotal | Status |
|---|---|---|---|---|---|
| Mono channel | SOURCE (A/B select) | 1 | 24 | 24 | ✓ |
| Mono channel | MUTE (ACTIVE/SOLO) | 1 | 24 | 24 | ✓ |
| Mono channel | AFL | 1 | 24 | 24 | ✓ |
| Mono channel | Channel Output SELECT | 1 | 24 | 24 | ✓ |
| Mono channel | FX-FOLLOW | 1 | 24 | 24 | ✓ |
| AUX return | ACTIVE | 1 | 4 | 4 | ✓ |
| AUX return | AFL | 1 | 4 | 4 | ✓ |
| Group | ACTIVE | 1 | 3 | 3 | ✓ |
| Group | AFL | 1 | 3 | 3 | ✓ |
| Monitor | Source-select (§8.1) | 1 | 1 | 1 | ✓ |
| Monitor | AFL/PFL alternation (§8.2) | 1 | 1 | 1 | ✓ |
| **Total** | | | | **136** | |

---

## Front-panel LEDs (indicators only — meter bridge LEDs not counted here)

### Per mono channel (× 24)

> ACTIVE (orange), SOLO (red), REC (red) LEDs are **integrated
> in their pushbutton bodies** (located on the fader PCB). They are MCU
> GPIO driven but are **not listed here** as separate indicators —
> they ship with the button.

| LED name | Color | Drive |
|---|---|---|
| LED-SOURCE-A | red | MCU GPIO |
| LED-SOURCE-B | green | MCU GPIO |
| LED-FX-FOLLOW-FOLLOW-PATH | orange | MCU GPIO |
| LED-FX-FOLLOW-FOLLOW-A | orange | MCU GPIO |
| LED-FX-FOLLOW-FOLLOW-B | orange | MCU GPIO |
| LED-HPF | orange | HPF button sec. 2 |
| LED-INSERT | blue | INSERT button sec. 2 |
| LED-PFL | red | PFL button sec. 2 |
| LED-PRE | orange | OUT-PRE/POST sec. 2, COM gated by DIR/PROC sec. 2 NO |
| LED-POST | orange | OUT-PRE/POST sec. 2, COM gated by DIR/PROC sec. 2 NO |
| LED-DIRECT | orange | DIR/PROC sec. 2 NC |
| **Per channel total** | **11** | |

**Mono channels subtotal: 11 × 24 = 264** ✓

### Other sections (estimates — update as sections are finalized)

| Section | Estimated LEDs | Status |
|---|---|---|
| AUX return × 4 | ~5–6 each → ~20–24 | ~ |
| Group × 3 | ~10–12 each → ~30–36 | ~ |
| AUX master × 4 | ~2–3 each → ~8–12 | ~ |
| CUE master | ~2 | ~ |
| Main Mix master | ~3–5 | ~ |
| Monitor section | ~3–5 | ~ |

**Estimated non-channel subtotal: ~66–84**

**Console total indicator LEDs: ~402–420** (round estimate: ~410)

> Meter bridge LEDs (signal-level meters) are driven by dedicated
> LED driver ICs on the meter PCBs — counted separately when the
> meter bridge is designed.

---

## Front-panel pushbuttons

### Per mono channel (× 24) — 10 per channel

**Momentary with integrated LED — on fader PCB (3 per channel):**

| Button | LED color | Relay / action | LED drive | Status |
|---|---|---|---|---|
| ACTIVE | orange (in button) | MUTE relay | MCU GPIO | ✓ |
| SOLO | red (in button) | AFL relay + others' MUTE (SIP opt.) | MCU GPIO | ✓ |
| REC | red (in button) | none — MIDI to DAW | MCU GPIO | ✓ |

Connection from fader PCB to digital logic PCB: TBD.

**Momentary without integrated LED (2 per channel):**

| Button | Separate LEDs | Relay / action | LED drive | Status |
|---|---|---|---|---|
| SOURCE | LED-SOURCE-A (red) + LED-SOURCE-B (green) | SOURCE relay | MCU GPIO | ✓ |
| FX-FOLLOW | LED-FX-FOLLOW-FOLLOW-PATH / -A / -B (3× orange) | FX-FOLLOW relay (3 modes) | MCU GPIO | ✓ |

**Latching DPDT (5 per channel):**

| Button | LED sec. 2 | Signal / relay | MCU GPIO in? | Status |
|---|---|---|---|---|
| HPF | orange | audio path direct | no | ✓ |
| INSERT | blue | audio path direct | no | ✓ |
| PFL | red | audio path direct | no | ✓ |
| OUT-PRE/POST | TBD × 2 | audio path direct | no | ✓ |
| DIR/PROC | 1 LED (DIRECT, TBD color) via sec. 2 NC; sec. 2 NO → PRE-POST sec. 2 COM (gates PRE/POST LEDs) | sec. 1 → digital/driver board; MCU GPIO or direct-to-driver TBD | TBD | ~ |

**Mono channel subtotal: 10 × 24 = 240**

### Other sections (estimates)

| Section | Estimated buttons | Status |
|---|---|---|
| AUX return × 4 | ~2 each (ACTIVE + AFL) → ~8 | ~ |
| Group × 3 | ~2 each (ACTIVE + AFL) → ~6 | ~ |
| AUX master × 4 | 1 each (PFL) → 4 | ~ |
| Monitor / master | ~2–4 (mono/check L+R + TBD) | ~ |

**Console total pushbuttons: ~258–262**

---

## Per-channel MCU I/O summary (confirmed)

| Signal type | Per channel | × 24 channels | Note |
|---|---|---|---|
| GPIO input — buttons | 5 (+1 TBD) | 120 (+24 TBD) | SOURCE, ACTIVE, SOLO, REC, FX-FOLLOW confirmed; DIR/PROC sec. 1 TBD (may bypass MCU — direct to relay driver) |
| GPIO output — LEDs | 8 | 192 | ACTIVE, SOLO, REC (integrated in button on fader PCB), LED-FX-FOLLOW-FOLLOW-PATH / -A / -B, LED-SOURCE-A + LED-SOURCE-B |
| Relay coil control lines | 10 (5 relays × 2) | 240 | via dedicated driver ICs, not direct GPIO |

LED-SOURCE-A and LED-SOURCE-B: MCU GPIO driven — updated on each SOURCE toggle.
ACTIVE, SOLO, REC: MCU GPIO driven — integrated in button body (fader PCB); GPIO wire routes fader PCB → digital logic PCB (TBD).
LED-FX-FOLLOW-FOLLOW-PATH, LED-FX-FOLLOW-FOLLOW-A, LED-FX-FOLLOW-FOLLOW-B: MCU GPIO driven — separate from the button.
LED-HPF, LED-INSERT, LED-PFL: latching button sec. 2 driven directly — no MCU GPIO output needed.
LED-DIRECT, LED-PRE, LED-POST: chained — DIR/PROC sec. 2 NC drives LED-DIRECT; sec. 2 NO feeds OUT-PRE/POST sec. 2 COM which drives LED-PRE or LED-POST depending on OUT-PRE/POST switch position. No MCU GPIO output needed for any of the three LEDs.

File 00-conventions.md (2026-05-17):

# 00 — Conventions

Global design conventions and electrical/implementation conventions for
CONSOLE. These apply throughout the project unless a specific section
explicitly overrides them.

This file is referenced by every other section. Read it before reading
any of the section files (`02-mono-channel.md`, etc.).

---

## Design conventions (signal-flow vocabulary)

- All balanced line outputs are **impedance-balanced TRS** (cold pin
  terminated, not actively driven) unless stated otherwise.
- Balanced inputs use a **differential buffer** (two high-impedance
  buffers, one for hot, one for cold) followed by an **unbalancing
  stage**.
- "Variable gain" = potentiometer controlling the gain of an active
  stage.
- "Fixed gain" = no user control, gain set by circuit.
- "Electronic switch" = signal-path switching element controlled by
  digital logic. In CONSOLE the standard implementation is a
  **signal relay** (see "Standard signal relay" below), not a CMOS /
  JFET analog switch IC. Used for SOLO, ACTIVE, AFL enable, CHANNEL
  SOURCE A/B select, master monitor source-select — anywhere the
  signal path is interrupted or rerouted under firmware control.
- "Mechanical switch" = front-panel toggle / push / rotary, direct
  user control.
- "Dual-gang pot" = one knob, two independent pot sections (gangs) —
  used for AUX sends (one gang picks up pre-fader, the other
  post-fader simultaneously) and for stereo CUE sends.
- "Stereo pot" = one knob, two ganged sections driving L and R in
  parallel (ganged behavior, not independent).
- Where the signal "becomes stereo" is noted explicitly. Before that
  point, the channel carries a single mono line; after that point, two
  lines (L and R) always travel together even if the content is
  momentarily mono.

---

## Electrical & implementation conventions

### Power supplies

- **±15V** rails for the audio signal path (all opamps, active
  switches in the audio path).
- **+3.3V** separate rail for LED indicators, MCU / digital logic,
  and standard-signal-relay coil drive (SOLO / ACTIVE / AFL
  electronic switches, firmware, front-panel pushbuttons).

### Grounds

- **AGND** (audio ground) — reference for all signal-path active and
  passive components.
- **DGND** (digital / indicator ground) — reference for LED indicators
  and future digital logic.
- **Chassis** — mechanical enclosure, reference for EMI filter caps
  and for TRS jack sleeves only.

AGND / DGND / Chassis are kept galvanically separate on a per-PCB
basis. The system-level joining scheme (star point at PSU, ferrite
bead, direct bond, etc.) is a global decision — see `10-open-tbd.md`.

### Passive component packages

- Default: **0603 SMD** for resistors and for capacitors under 1 µF.
- Capacitors ≥ 1 µF are free from the 0603 constraint — typically
  bipolar electrolytic (signal-path coupling) or polarized
  electrolytic (power-rail bulk), SMD or radial as volume requires.

### IC packages

- Default: **SOIC** for all opamps and analog switches.
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

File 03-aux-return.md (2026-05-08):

# 03 — AUX Returns — Stereo Input Channels (× 4)

There are **4 stereo AUX returns**, all identical in topology. They
are intended as stereo line-level inputs (effects returns, stereo
sources, etc.) that contribute to the internal buses but do **not**
have any output to the outside world.

Each AUX return follows the structure described below. References to
"the AUX return" or "this channel" mean a single one of the four —
multiply by 4 for the actual count.

---

## 3.1 Input stage

- Two balanced TRS inputs: **L** and **R**, each with its own
  differential buffer + unbalancing stage + variable gain.
- The gain control is a **stereo pot** (one knob, L and R gangs
  move together). No Direct Out.

## 3.2 MONO switch

Mechanical switch. When active, an opamp mixes L + R and the result
is replicated onto both L and R lines. When inactive, L and R remain
independent.

**Convention**: the channel always carries two lines (L and R)
throughout, even when MONO is engaged — it just happens that both
carry the same (premixed) signal in that case.

## 3.3 Meter buffers (× 2)

One buffer per line, feeding the LED meter bridge (stereo meter).
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

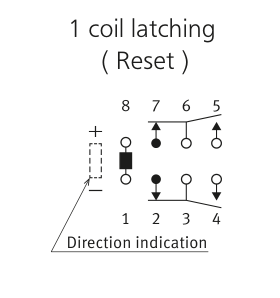
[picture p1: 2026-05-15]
datasheets/AGQ210A03.png

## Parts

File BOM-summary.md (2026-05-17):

# BOM Summary — Component Numerosity Reference

> Counts all major components except: resistors, capacitors, diodes, PCB-to-PCB connectors.
> Faders excluded from potentiometer and knob counts.
> **Status:** ✓ = confirmed from finalized blocks; ~ = estimated from sections still conceptual.

---

## 1. Relays

Single type throughout: **AGQ210A03** (Panasonic, DPDT 2 form C, 1-coil latching, 3 V coil)

| Function | Per unit | Units | Total | Status |
|---|---|---|---|---|
| SOURCE (Input A / B select) | 1 | 24 mono ch | 24 | ✓ |
| MUTE (series + shunt) | 1 | 24 mono ch | 24 | ✓ |
| AFL (post-pan stereo tap) | 1 | 24 mono ch | 24 | ✓ |
| DIRECT OUT SELECT (Input A / channel signal) | 1 | 24 mono ch | 24 | ✓ |
| FX-FOLLOW | 1 | 24 mono ch | 24 | ✓ |
| ACTIVE (stereo, both gangs on one coil) | 1 | 4 AUX return | 4 | ✓ |
| AFL (stereo, both gangs on one coil) | 1 | 4 AUX return | 4 | ✓ |
| ACTIVE (stereo, both gangs on one coil) | 1 | 3 groups | 3 | ✓ |
| AFL (stereo, both gangs on one coil) | 1 | 3 groups | 3 | ✓ |
| Monitor source-select (Main Mix / Solo summer) | 1 | monitor | 1 | ✓ |
| Monitor AFL / PFL alternation | 1 | monitor | 1 | ✓ |
| **TOTAL** | | | **136** | ✓ |

---

## 2. ICs / Opamps

### 2a. Mono channels (×24) — confirmed

| IC | Package | Function | Per ch | Total | Status |
|---|---|---|---|---|---|
| OPA1679 | Quad SOIC | Input buffers — A-hot, A-cold, B-hot, B-cold (unity-gain followers) | 1 | 24 | ✓ |
| OPA1679 | Quad SOIC | Balanced receivers — Input A + B, All-Inverting topology | 1 | 24 | ✓ |
| NE5532 | Dual SOIC | HPF (Sallen-Key 2nd order) + Insert Return receiver | 1 | 24 | ✓ |
| NE5532 | Dual SOIC | Post-fader amp +10 dB — 1 IC shared by 2 ch on fader PCB | 0.5 | 12 | ✓ |
| NE5532 | Dual SOIC | Active pan L + R (Self-style, both halves used) | 1 | 24 | ✓ |
| TL072 | Dual SOIC | Dual meter buffer — active (pre-MUTE) + inactive (SOURCE relay set 2) | 1 | 24 | ✓ |
| **Mono channel subtotal** | | | | **132** | ✓ |

**Per tipo IC — mono ch (per l'ordine; altre sezioni ancora TBD):**

| IC | Totale mono ch | Altre sezioni | Status |
|---|---|---|---|
| OPA1679 | **48** | TBD | ✓ / ~ |
| NE5532 | **60** | TBD | ✓ / ~ |
| TL072 | **24** | TBD | ✓ / ~ |

### 2b. Other sections — TBD (conceptual)

| Section | Notes | Status |
|---|---|---|
| AUX return ×4 | Summing amp, post-fader amps, MONO mixer, balance amp, meter buffers — IC TBD | ~ |
| Group ×3 | Summing amp, post-fader amps, MONO mixer, balance amp, AUX mode mix — IC TBD | ~ |
| AUX master ×4 | PRE + POST summing amps, variable gain stage — IC TBD | ~ |
| CUE master | Stereo summing amp — IC TBD | ~ |
| Main Mix master | Stereo summing amp + SSL-style parallel compressor (VCA / dedicated IC) — IC TBD | ~ |
| Monitor | AFL summer, PFL summer, mono/check network — IC TBD | ~ |

---

## 3. Potentiometers (faders excluded)

### 3a. Mono channels (×24)

| Function | Type | Value | Per ch | Total | Status |
|---|---|---|---|---|---|
| Gain — Input A + B (stesso part, All-Inverting Rf) | Single-gang | 10 kΩ LOG | 2 | 48 | ✓ |
| AUX 1–4 send — tutti stesso part, gang 1 pre-fader + gang 2 post-fader | Dual-gang | TBD | 4 | 96 | ~ |
| CUE send — both gangs pre-fader → CUE L / CUE R | Dual-gang | TBD | 1 | 24 | ~ |
| Pan — Self active panpot (L + R, center-detent preferred) | Dual-gang | 10 kΩ LIN | 1 | 24 | ✓ |
| **Mono channel subtotal** | | | **8 / ch** | **192** | |

### 3b. AUX returns (×4)

| Function | Type | Value | Per unit | Total | Status |
|---|---|---|---|---|---|
| Stereo gain (L + R ganged) | Dual-gang | TBD | 1 | 4 | ~ |
| Active balance (L / R) | Dual-gang | TBD | 1 | 4 | ~ |
| CUE send (stereo, pre-fader) | Dual-gang | TBD | 1 | 4 | ~ |
| **AUX return subtotal** | | | **3 / return** | **12** | |

### 3c. Groups (×3)

| Function | Type | Value | Per unit | Total | Status |
|---|---|---|---|---|---|
| AUX 1–4 send (tutti stesso part, pre + post gangs) | Dual-gang | TBD | 4 | 12 | ~ |
| Active balance (L / R) | Dual-gang | TBD | 1 | 3 | ~ |
| CUE send (stereo, pre-fader) | Dual-gang | TBD | 1 | 3 | ~ |
| **Group subtotal** | | | **6 / group** | **18** | |

### 3d. Master sections

| Function | Type | Value | Section | Total | Status |
|---|---|---|---|---|---|
| Variable gain (post PRE/POST select) | Single-gang | TBD | AUX master ×4 | 4 | ~ |
| Stereo gain (CUE bus) | Dual-gang | TBD | CUE master | 1 | ~ |
| "In front balance" (Main Mix level behind AFL) | TBD | TBD | Monitor | 1 | ~ |
| **Master subtotal** | | | | **6** | |

### Potentiometer total: 192 + 12 + 18 + 6 = **228**

---

## 4. Knobs

> 1 knob per potentiometer + 1 per rotary switch. Fader caps esclusi (§7).
> Colori disponibili (Tayda 15×13 mm plastic knob): **nero, grigio, blu, rosso** — da assegnare per funzione (TBD).

| Funzione | Pot/switch | Count | Colore | Status |
|---|---|---|---|---|
| Gain (Input A + B) — mono ch | Single-gang | 48 | TBD | ~ |
| AUX 1–4 send — mono ch | Dual-gang | 96 | TBD | ~ |
| CUE send — mono ch | Dual-gang | 24 | TBD | ~ |
| Pan — mono ch | Dual-gang | 24 | TBD | ~ |
| Stereo gain — AUX return | Dual-gang | 4 | TBD | ~ |
| Active balance — AUX return | Dual-gang | 4 | TBD | ~ |
| CUE send — AUX return | Dual-gang | 4 | TBD | ~ |
| AUX 1–4 send — groups | Dual-gang | 12 | TBD | ~ |
| Active balance — groups | Dual-gang | 3 | TBD | ~ |
| CUE send — groups | Dual-gang | 3 | TBD | ~ |
| Variable gain — AUX master | Single-gang | 4 | TBD | ~ |
| Stereo gain — CUE master | Dual-gang | 1 | TBD | ~ |
| "In front balance" — monitor | TBD | 1 | TBD | ~ |
| Routing — post-pan (mono ch) | Rotary 4-pos | 24 | TBD | ~ |
| Routing — post-balance (AUX return) | Rotary 4-pos | 4 | TBD | ~ |
| **TOTAL** | | **256** | | |

---

## 5. Rotary switches (routing)

| Function | Type | Per unit | Section | Total | Status |
|---|---|---|---|---|---|
| Post-pan routing → Main / G1 / G2 / G3 | 2-gang, 4-position, mechanical | 1 | 24 mono ch | 24 | ~ |
| Post-balance routing → Main / G1 / G2 / G3 | 2-gang, 4-position, mechanical | 1 | 4 AUX return | 4 | ~ |
| **TOTAL** | | | | **28** | |

---

## 6. Pushbuttons

All front-panel controls share the same physical pushbutton body. Three sub-categories:

- **Momentary with integrated LED** — the LED is inside the button body and is NOT listed separately in §8. Firmware drives both the LED and the relay.
- **Momentary without integrated LED** — spring-return; firmware manages relay and any separate LEDs. **Requires cap.**
- **Latching DPDT** — push-push self-locking; section 1 carries the audio or control signal, section 2 drives a separate LED (those LEDs ARE listed in §8). No firmware involved. **Requires cap.**

### 6a. Momentary — with integrated LED (on fader PCB)

> These 3 LEDs are integral to the button — **not** listed separately in §8.
> Location: fader PCB (same board as fader and post-fader amp). Connection to digital logic PCB: TBD.

| Function | LED color | Per ch | Total | Status |
|---|---|---|---|---|
| ACTIVE | Orange | 1 | 24 | ✓ |
| SOLO | Red | 1 | 24 | ✓ |
| REC (MIDI only — no audio relay) | Red | 1 | 24 | ✓ |
| **Subtotal momentary w/ LED** | | **3 / ch** | **72** | ✓ |

### 6b. Momentary — without integrated LED

| Function | Separate LEDs | Per unit | Section | Total | Status |
|---|---|---|---|---|---|
| SOURCE (A/B toggle) | 2 sep. (red A + green B), MCU GPIO | 1 | 24 mono ch | 24 | ✓ |
| FX-FOLLOW (cycles 3 modes) | 3 sep. orange, MCU GPIO | 1 | 24 mono ch | 24 | ✓ |
| ACTIVE | TBD | 1 | 4 AUX return | 4 | ~ |
| AFL | TBD | 1 | 4 AUX return | 4 | ~ |
| ACTIVE | TBD | 1 | 3 groups | 3 | ~ |
| AFL | TBD | 1 | 3 groups | 3 | ~ |
| PFL | TBD | 1 | 4 AUX master | 4 | ~ |
| Mono/check L | TBD | 1 | monitor | 1 | ~ |
| Mono/check R | TBD | 1 | monitor | 1 | ~ |
| **Subtotal momentary no LED** | | | | **~68** | |

### 6c. Latching DPDT (push-push self-locking — LED driven by button sec. 2, listed in §8)

#### Mono channels (×24)

| Function | LED sec. 2 | Per ch | Total | Status |
|---|---|---|---|---|
| HPF in / bypass | Orange | 1 | 24 | ✓ |
| INSERT in / bypass | Blue | 1 | 24 | ✓ |
| PFL on / off | Red | 1 | 24 | ✓ |
| OUT-PRE/POST select (2-position) | TBD ×2 | 1 | 24 | ✓ |
| DIR/PROC (controls DIRECT OUT SELECT relay on input PCB) | TBD | 1 | 24 | ~ |
| **Mono channel subtotal** | | **5 / ch** | **120** | |

#### Other sections

| Function | LED | Per unit | Section | Total | Status |
|---|---|---|---|---|---|
| PRE / POST send select | TBD | 1 | AUX master ×4 | 4 | ~ |
| Group → Main Mix on / off | TBD | 1 | Group ×3 | 3 | ~ |
| AUX mode — split / premix (one per AUX) | TBD | 4 | Group ×3 | 12 | ~ |
| **Other subtotal** | | | | **19** | |

### Subtotal latching: 120 + 19 = **139**

### Caps total (momentary no LED + latching): ~68 + 139 = **~207**

---

## 7. Faders

> Esclusi dai conteggi di pot e knob.

| Part | Tipo | Per unità | Sezione | Totale | Status |
|---|---|---|---|---|---|
| Alps RSA0N111900Q | Fader mono lineare | 1 | 24 mono ch | 24 | ✓ |
| Fader stereo gruppo | TBD | 1 | 3 groups | 3 | ~ |
| Fader master / altri | TBD | TBD | Main mix + altri | TBD | ~ |

---

## 8. Indicator LEDs (meter bridge bargraph LEDs excluded — counted separately)

### 8a. Mono channels (×24) — confirmed

> ACTIVE, SOLO, REC LEDs are integrated in their pushbutton bodies — **not listed here** (see §6a).

| Function | Color | Drive source | Per ch | Total | Status |
|---|---|---|---|---|---|
| LED-SOURCE-A | Red | MCU GPIO | 1 | 24 | ✓ |
| LED-SOURCE-B | Green | MCU GPIO | 1 | 24 | ✓ |
| LED-FX-FOLLOW-FOLLOW-PATH | Orange | MCU GPIO | 1 | 24 | ✓ |
| LED-FX-FOLLOW-FOLLOW-A | Orange | MCU GPIO | 1 | 24 | ✓ |
| LED-FX-FOLLOW-FOLLOW-B | Orange | MCU GPIO | 1 | 24 | ✓ |
| LED-HPF | Orange | HPF button sec. 2 | 1 | 24 | ✓ |
| LED-INSERT | Blue | INSERT button sec. 2 | 1 | 24 | ✓ |
| LED-PFL | Red | PFL button sec. 2 | 1 | 24 | ✓ |
| LED-PRE | Orange | OUT-PRE/POST sec. 2, gated by DIR/PROC | 1 | 24 | ✓ |
| LED-POST | Orange | OUT-PRE/POST sec. 2, gated by DIR/PROC | 1 | 24 | ✓ |
| LED-DIRECT | Orange | DIR/PROC sec. 2 NC | 1 | 24 | ✓ |
| **Mono channel subtotal** | | | **11 / ch** | **264** | ✓ |

**By color — mono channels only:**

| Color | Count | Notes |
|---|---|---|
| Red | 48 | LED-SOURCE-A (24) + LED-PFL (24) |
| Green | 24 | LED-SOURCE-B |
| Orange | 168 | LED-FX-FOLLOW ×3 (72) + LED-HPF (24) + LED-PRE + LED-POST + LED-DIRECT (72) |
| Blue | 24 | LED-INSERT |

### 8b. Other sections — estimated

| Section | Estimated LEDs | Status |
|---|---|---|
| AUX return ×4 | ~5–6 each → **~20–24** | ~ |
| Group ×3 | ~10–12 each → **~30–36** | ~ |
| AUX master ×4 | ~2–3 each → **~8–12** | ~ |
| CUE master | **~2** | ~ |
| Main Mix master | **~3–5** | ~ |
| Monitor section | **~3–5** | ~ |
| **Other sections subtotal** | **~66–84** | ~ |

### Indicator LED total: **~330–348** (mid estimate ~339)

---

## 9. TRS Jacks

Single type throughout: **Rean RJ5VM** — TRS stereo-with-switch (5-contact). Switch contacts (TIP-SW / RING-SW) used for idle-noise termination — they short TIP↔TIP-SW and RING↔RING-SW when no plug is inserted — on: Input A, Input B, and Insert Return. Left unconnected on all output jacks and Insert Send.

| Function | Per unit | Section | SW contacts used | Total | Status |
|---|---|---|---|---|---|
| Input A | 1 | 24 mono ch | ✓ idle termination | 24 | ✓ |
| Input B | 1 | 24 mono ch | ✓ idle termination | 24 | ✓ |
| Channel Output (rear panel, switchable: direct / processed) | 1 | 24 mono ch | — | 24 | ✓ |
| Insert Send (impedance-balanced) | 1 | 24 mono ch | — | 24 | ✓ |
| Insert Return | 1 | 24 mono ch | ✓ idle termination | 24 | ✓ |
| Input L | 1 | 4 AUX return | TBD | 4 | ~ |
| Input R | 1 | 4 AUX return | TBD | 4 | ~ |
| Insert Send | 1 | 3 groups | — | 3 | ~ |
| Insert Return | 1 | 3 groups | TBD | 3 | ~ |
| Post-Fader Out L (impedance-balanced) | 1 | 3 groups | — | 3 | ~ |
| Post-Fader Out R (impedance-balanced) | 1 | 3 groups | — | 3 | ~ |
| AUX n OUT (impedance-balanced) | 1 | 4 AUX master | — | 4 | ~ |
| CUE OUT L (impedance-balanced) | 1 | CUE master | — | 1 | ~ |
| CUE OUT R (impedance-balanced) | 1 | CUE master | — | 1 | ~ |
| Main Out A L (impedance-balanced) | 1 | Main mix | — | 1 | ~ |
| Main Out A R (impedance-balanced) | 1 | Main mix | — | 1 | ~ |
| Main Out B L (impedance-balanced) | 1 | Main mix | — | 1 | ~ |
| Main Out B R (impedance-balanced) | 1 | Main mix | — | 1 | ~ |
| Main Insert Send L | 1 | Main mix | — | 1 | ~ |
| Main Insert Send R | 1 | Main mix | — | 1 | ~ |
| Main Insert Return L | 1 | Main mix | TBD | 1 | ~ |
| Main Insert Return R | 1 | Main mix | TBD | 1 | ~ |
| **TOTAL** | | | | **154** | |

> Monitor output jacks not included (TBD).

---

## Grand summary — per part number

> Questo è il reference per l'ordine. Items con part number TBD si sdoppieranno in più righe una volta definiti i valori.

| Part number / tipo | Descrizione | Qty | In possesso | Da comprare | Status |
|---|---|---|---|---|---|
| **AGQ210A03** | Relay DPDT latching 3 V (Panasonic) | 136 | 121 | 15 | ✓ |
| **OPA1679** | Quad opamp SOIC-14 | ≥48 | — | ≥48 | ✓ mono ch; altre sez. TBD |
| **NE5532** | Dual opamp SOIC-8 | ≥60 | — | ≥60 | ✓ mono ch; altre sez. TBD |
| **TL072** | Dual opamp SOIC-8 | ≥24 | — | ≥24 | ✓ mono ch; altre sez. TBD |
| **Alps RSA0N111900Q** | Fader mono lineare | 24 | 24 | 0 | ✓ |
| Fader stereo (part TBD) | Fader stereo — groups + master | TBD | — | TBD | ~ |
| **Rean RJ5VM** | Jack TRS 5-contact con switch | 154 | — | 154 | ✓/~ |
| Pot single-gang 10 kΩ LOG — [Tayda](https://www.taydaelectronics.com/10k-ohm-logarithmic-taper-potentiometer-round-shaft-pcb-9mm.html) | Gain (Input A + B, mono ch) | 48 | — | 48 | ✓ |
| Pot dual-gang 10 kΩ LIN — [Tayda](https://www.taydaelectronics.com/10k-ohm-linear-dual-taper-potentiometer-round-shaft-pcb-9mm.html) | Pan (mono ch) | 24 | — | 24 | ✓ |
| Pot dual-gang (value TBD) | AUX send (96 ch + 12 gr) + CUE send (24 ch + 4 ret + 3 gr) + balance (4 ret + 3 gr) + CUE master (1) = 147 | 147 | — | 147 | ~ |
| Pot single-gang (value TBD) | AUX master variable gain | 4 | — | 4 | ~ |
| Pot TBD (gang + value TBD) | Monitor "in front balance" | 1 | — | 1 | ~ |
| Rotary switch 2-gang 4-pos (part TBD) | Routing post-pan + post-balance | 28 | — | 28 | ~ |
| Pushbutton momentary w/ integrated LED (part TBD) | ACTIVE/SOLO/REC — fader PCB | 72 | — | 72 | ✓ |
| Pushbutton momentary no LED (part TBD) | Channel source, HPF/INS bypass, AUX/group/master controls | ~68 | 300 | 0 | ✓/~ |
| Pushbutton latching DPDT (part TBD) | HPF, INSERT, PFL, PRE/POST, DIR/PROC, AUX mode | ~139 | 300 | 0 | ✓/~ |
| Button cap (part TBD) | Per momentary no LED + latching | ~207 | 300 | 0 | ~ |
| Knob (colore TBD) — [Tayda](https://www.taydaelectronics.com/catalogsearch/result/?q=15x13mm+plastic+knob) | 1 per pot + 1 per rotary | 256 | — | 256 | ~ |
| Indicator LED (color mix — see §8) | Separate LEDs, non integrati nei tasti | ~315 | — | ~315 | ✓/~ |

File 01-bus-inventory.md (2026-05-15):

# 01 — Bus inventory

Total: **7 stereo bus + 9 mono bus** = 16 distinct buses, i.e. 23
summing lines to route and solder.

---

## Stereo buses (7)

| # | Name | Fed by |
|---|---|---|
| 1 | Main Mix | Channels (via 4-pos rotary), AUX returns (via 4-pos rotary), groups (via main on/off switch) |
| 2 | Group 1 | Channels, AUX returns (via 4-pos rotary) |
| 3 | Group 2 | Channels, AUX returns (via 4-pos rotary) |
| 4 | Group 3 | Channels, AUX returns (via 4-pos rotary) |
| 5 | AFL | All channels / AUX returns / groups (via AFL electronic switch, post-fader, post-pan/post-balance) |
| 6 | CUE | Channels, AUX returns, groups (via CUE dual-gang pot, pre-fader) |
| 7 | PFL stereo | AUX returns and groups (via PFL stereo switch, pre-fader). Mono channels do NOT feed this bus. |

---

## Mono buses (9)

| # | Name | Fed by |
|---|---|---|
| 1 | AUX 1 pre | 24 channels + 3 groups (pre-fader gang of AUX1 dual-gang). AUX returns do NOT feed any AUX bus. |
| 2 | AUX 1 post | 24 channels + 3 groups (post-fader gang of AUX1 dual-gang). AUX returns do NOT feed any AUX bus. |
| 3 | AUX 2 pre | 24 channels + 3 groups |
| 4 | AUX 2 post | 24 channels + 3 groups |
| 5 | AUX 3 pre | 24 channels + 3 groups |
| 6 | AUX 3 post | 24 channels + 3 groups |
| 7 | AUX 4 pre | 24 channels + 3 groups |
| 8 | AUX 4 post | 24 channels + 3 groups |
| 9 | PFL mono | 24 mono channels (PFL switch, pre-fader) + 4 AUX master PFL pushes |

Note: **PFL mono and PFL stereo are separate buses.** They are merged
only downstream at the PFL summer inside the master monitor (see
`08-monitor.md`).

**No AUX return feeds back into any AUX bus** — deliberate, to avoid
feedback loops. The AUX returns do NOT have AUX sends.

---

## Logical buses (1)

These are NOT audio buses — they are digital wired-OR lines monitored
by firmware.

| # | Name | Fed by |
|---|---|---|
| 1 | PFL DETECT | 24 mono channels (per-channel diode wired-OR from the PFL DPDT Sec2). Whether AUX masters / AUX returns / groups also feed this bus to drive the master-monitor source-select is currently TBD — see `10-open-tbd.md`. |

PFL DETECT goes HIGH whenever at least one PFL switch anywhere on
the console is engaged. Firmware reads it to drive the master
monitor source-select (§8.1) — switching the monitor source from
Main Mix to the Solo summer when any PFL is active.

---

## §11 — Counts (quick reference)

| Item | Count |
|---|---|
| Mono input channels | 24 |
| Stereo AUX returns | 4 |
| Stereo groups | 3 |
| AUX masters (mono) | 4 |
| AUX buses (mono) | 8 (4 pre + 4 post) |
| Stereo buses | 7 (Main, G1, G2, G3, AFL, CUE, PFL stereo) |
| Mono buses | 9 (8 AUX + PFL mono) |
| Logical buses | 1 (PFL DETECT — wired-OR digital, not a summing line) |
| Total summing lines | 7 stereo × 2 lines + 9 mono × 1 line = **23** |
| Main outputs | 2 pairs (A + B), 4 TRS jacks total |
| Insert points | 24 (channels) + 3 (groups) + 1 (main mix) = 28 |
| Channel Outputs | 24 (TRS rear-panel, switchable: full-differential from Input A / processed signal via PRE-POST switch; controlled by Channel Output SELECT relay) |
| Post-Fader Outs | 24 (channels, mono) + 6 (3 groups × L/R) = 30. (AUX returns do NOT have Post-Fader Outs.) |
| AUX master OUT jacks | 4 (one per AUX master, TRS impedance-balanced) |
| CUE master OUT jacks | 2 (L + R, TRS impedance-balanced) |

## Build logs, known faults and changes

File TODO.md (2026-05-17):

# TODO — Prossimi passi (in ordine di priorità)

1. Rivisitare il layout frontale su Illustrator per inserire i nuovi pulsanti
2. Decidere il sistema di summing e calcolare le resistenze di bus relative

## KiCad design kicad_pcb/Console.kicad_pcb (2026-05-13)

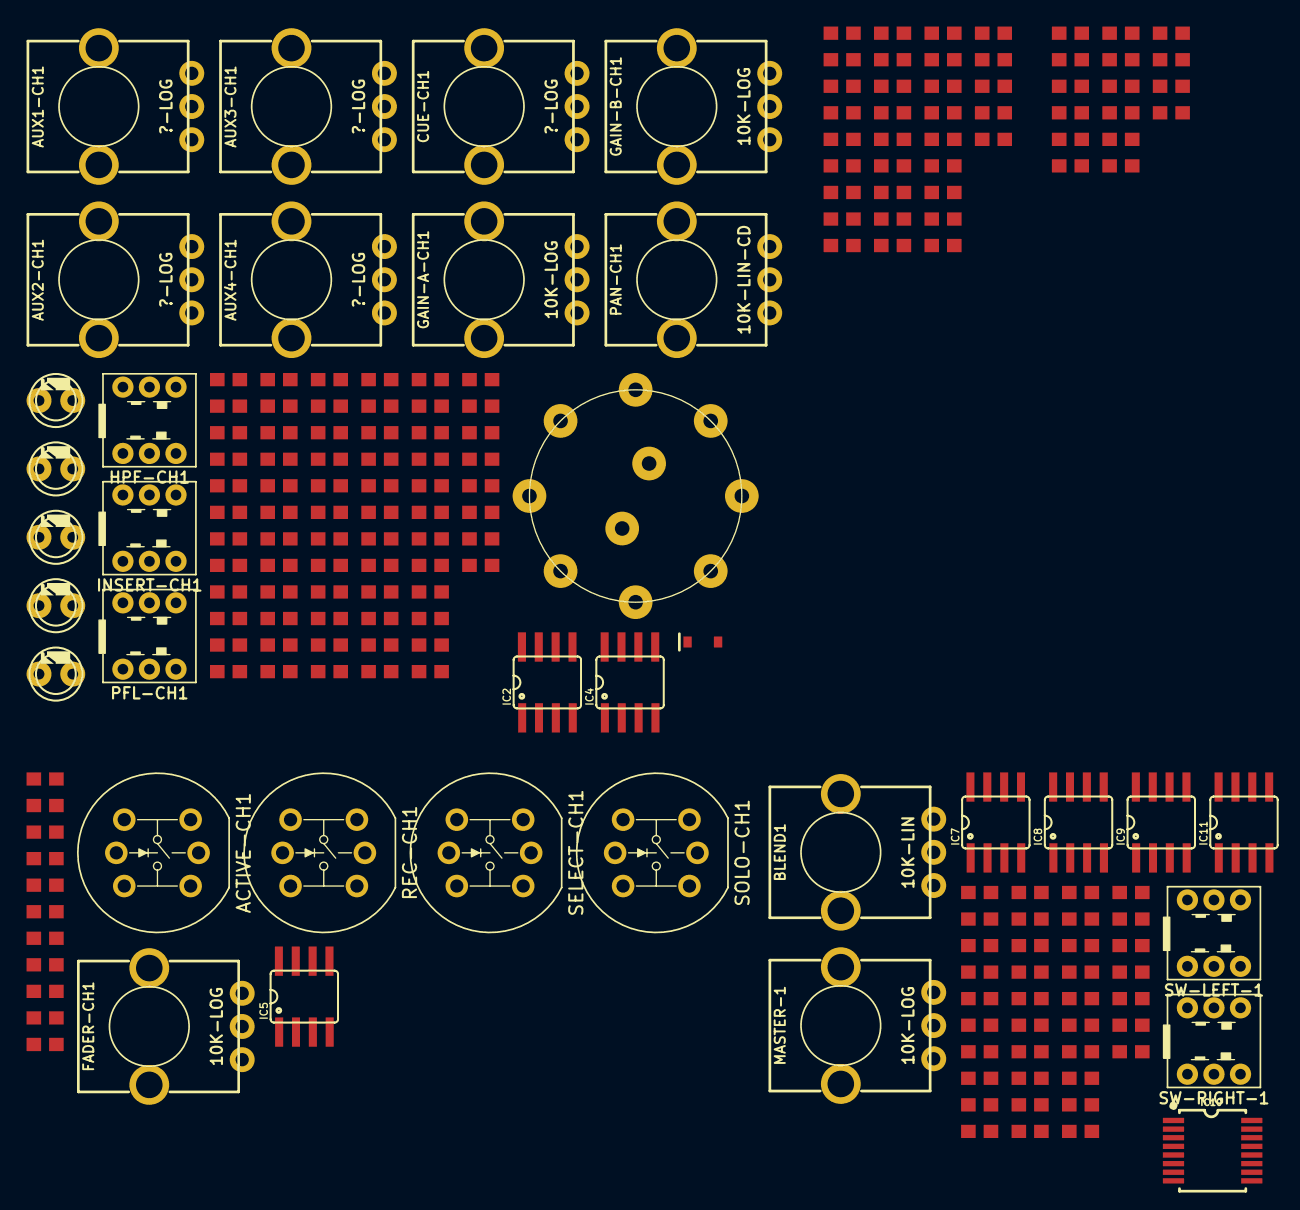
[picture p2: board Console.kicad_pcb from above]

Board: 2 copper layers, 199 parts (0 on the bottom side), 112 nets, no tracks yet.

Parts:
ACTIVE-CH1: KS-01 yellow; KS-01
AUX1-CH1, AUX2-CH1, AUX3-CH1, AUX4-CH1: ?-LOG; POTENTIOMETER-9MM
BLEND1: 10K-LIN; POTENTIOMETER-9MM
C1, C2, C4, C5, C10, C11, C13, C14, C29, C30, C32, C33, C83, C84, C86, C87, C89, C90, C92, C93: 470pF; 0603
C3, C6, C9, C12, C28, C31, C82, C85, C88, C91: 47pF; 0603
C36, C37, C53: 100pF; 0603
C39, C40, C41: 220nF; 0603
C43, C44, C45, C46, C47, C48, C54, C55, C56, C57, C60, C61, C74, C75, C76, C77: 100nF; 0603
C58, C59: 220pF; 0603
C63, C64, C68, C69, C71: 0603
C80, C81: 47nF; 0603
CUE-CH1: ?-LOG; POTENTIOMETER-9MM
D1: 4148; SOD323
FADER-CH1: 10K-LOG; POTENTIOMETER-9MM
FB1, FB2, FB3, FB4, FB9, FB10, FB11, FB12, FB13, FB14: 330R@100MHz; 0603
GAIN-A-CH1: 10K-LOG; POTENTIOMETER-9MM
GAIN-B-CH1: 10K-LOG; POTENTIOMETER-9MM
HPF-CH1: SWITCH_PUSH_7X7-POLARIZED
IC2, IC4, IC5: NE5532; SO-8
IC7: AD797; SO-8
IC8, IC9: SO-8
IC10: ADG1436; TSSOP-16
IC11: Opamp_Dual; SO-8
INSERT-CH1: SWITCH_PUSH_7X7-POLARIZED
LED-HPF-CH1: orange; LED3MM
LED-INSERT-CH1: blue; LED3MM
LED-MONITOR-A-CH1: red; LED3MM
LED-MONITOR-B-CH1: green; LED3MM
LED-PFL-CH1: red; LED3MM
MASTER-1: 10K-LOG; POTENTIOMETER-9MM
PAN-CH1: 10K-LIN-CD; POTENTIOMETER-9MM
PFL-CH1: SWITCH_PUSH_7X7-POLARIZED
R1, R2, R3, R4: 100K; 0603
R5, R6, R7, R10, R11, R12, R13, R14: 1K; 0603
R8, R15: 100R; 0603
R9, R16, R17, R22, R26, R31, R77, R80, R85, R86: 47K; 0603
R18, R19, R20, R21, R42, R43, R66, R67, R72, R73, R74, R75: 10K; 0603
R23: 5.1K; 0603
R24: 1.3K; 0603
R25: 62K; 0603
R27, R87, R88: 22K; 0603
R28, R29, R78, R79, R81, R82, R89, R92, R93: 75R; 0603
R30, R32, R33, R34, R60, R61, R62, R63, R64: R; 0603
R35: 680R; 0603
R36: 4.7K; 0603
R37, R40, R41, R83, R84: 2.2K; 0603
R38, R39: 3.3K; 0603
R44, R45, R46, R47, R48, R49, R50, R51, R52, R53, R54, R55, R56, R57, R58, R59, R65, R90, R91: 0603
R68, R69, R70, R71: 15K; 0603
R76: 49.9K; 0603
REC-CH1: KS01 red; KS-01
ROUTE-CH1: ROTARY-RS16
SELECT-CH1: KS-01 green; KS-01
SOLO-CH1: KS01 red; KS-01
SW-LEFT-1: SWITCH_PUSH_7X7-POLARIZED
SW-RIGHT-1: SWITCH_PUSH_7X7-POLARIZED

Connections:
+5VD: HPF-CH1.2-C (C), INSERT-CH1.2-C (C), PFL-CH1.2-C (C)
+15V: C44.1, C45.1, C47.1, C54.1, C56.1, C60.1, C74.1, C76.1, IC2.8 (V+), IC4.8 (V+), IC5.8 (V+), IC7.7 (V+), IC8.8 (V+), IC9.8 (V+)
-15V: C43.2, C46.2, C48.2, C55.2, C57.2, C61.2, C75.2, C77.2, IC2.4 (V-), IC4.4 (V-), IC5.4 (V-), IC7.4 (V-), IC8.4 (V-), IC9.4 (V-)
GND: AUX1-CH1.1 (CCW), AUX2-CH1.1 (CCW), AUX3-CH1.1 (CCW), AUX4-CH1.1 (CCW), BLEND1.2 (WIPER), C37.2, C43.1, C44.2, C45.2, C46.1, C47.2, C48.1, C54.2, C55.1, C56.2, C57.1, C60.2, C61.1, C68.2, C74.2, C75.1, C76.2, C77.1, CUE-CH1.1 (CCW), FADER-CH1.1, IC7.3 (+), IC8.3 (+), IC8.5 (+), PAN-CH1.3 (CW), PFL-CH1.1-NC (NC), R1.2, R2.2, R3.2, R4.2, R9.2, R16.2, R17.2, R21.2, R22.2, R23.2, R25.2, R26.2, R31.2, R37.2, R42.1, R43.1, R74.2, R77.2, R80.2, R85.2, R86.2
GNDD: ACTIVE-CH1.SW-B, R30.2, R32.2, R33.2, R34.2, R60.2, R61.2, R62.2, R63.2, R64.2, REC-CH1.SW-B, SELECT-CH1.SW-B, SOLO-CH1.SW-B
GND_CHASSIS: C3.2, C6.2, C9.2, C12.2, C28.2, C31.2, C82.2, C85.2, C88.2, C91.2
LEFT-OUT: IC11.1, IC11.2 (-), R87.2
unnamed: C2.2, FB2.1
unnamed: C1.1, FB1.1
unnamed: ACTIVE-CH1.LED-C, R61.1
unnamed: AUX1-CH1.3 (CW), AUX2-CH1.3 (CW), AUX3-CH1.3 (CW), AUX4-CH1.3 (CW), CUE-CH1.3 (CW)
unnamed: AUX1-CH1.2 (WIPER), R48.2
unnamed: AUX2-CH1.2 (WIPER), R54.2
unnamed: AUX3-CH1.2 (WIPER), R56.2
unnamed: AUX4-CH1.2 (WIPER), R58.2
unnamed: C11.2, FB4.1
unnamed: C10.1, FB3.1
unnamed: BLEND1.1 (CCW), R70.1, R71.2
unnamed: BLEND1.3 (CW), R68.2, R69.1
unnamed: C90.2, FB14.1
unnamed: C89.1, FB13.1
unnamed: C1.2, C2.1, C3.1
unnamed: C4.1, FB1.2
unnamed: C4.2, C5.1, C6.1
unnamed: C5.2, FB2.2
unnamed: C9.1, C10.2, C11.1
unnamed: C12.1, C13.2, C14.1
unnamed: C13.1, FB3.2
unnamed: C14.2, FB4.2
unnamed: R17.1, R29.1
unnamed: C28.1, C29.2, C30.1
unnamed: C29.1, FB9.1
unnamed: C30.2, FB10.1
unnamed: C31.1, C32.2, C33.1
unnamed: C36.2, IC2.1, R20.1
unnamed: C39.2, C40.1, R23.1
unnamed: C40.2, C41.1, R24.1
unnamed: C53.2, R35.1, R36.1
unnamed: C63.2, IC7.6, R65.1, R66.2
unnamed: C64.2, IC8.1, R67.1
unnamed: R69.2, R78.2
unnamed: C69.2, IC9.1, R75.1
unnamed: C71.2, IC8.7, R76.1
unnamed: R77.1, R81.1
unnamed: R80.1, R82.1
unnamed: C80.1, R87.1
unnamed: C81.1, R88.1
unnamed: C82.1, C83.2, C84.1
unnamed: C83.1, FB11.1
unnamed: C84.2, FB12.1
unnamed: C85.1, C86.2, C87.1
unnamed: C88.1, C89.2, C90.1
unnamed: C91.1, C92.2, C93.1
unnamed: C92.1, FB13.2, R92.1
unnamed: C93.2, FB14.2, R93.1
unnamed: CUE-CH1.2 (WIPER), R90.2
unnamed: GAIN-A-CH1.2, GAIN-A-CH1.3, R8.2
unnamed: GAIN-B-CH1.2, GAIN-B-CH1.3, R15.2
unnamed: HPF-CH1.1-C (C), INSERT-CH1.1-NC (NC), R28.1
unnamed: C39.1, HPF-CH1.1-NC (NC)
unnamed: HPF-CH1.1-NO (NO), R26.1
unnamed: R6.1, R7.2
unnamed: R12.1, R13.2
unnamed: R5.1, R6.2
unnamed: GAIN-A-CH1.1, R7.1, R10.1
unnamed: R11.1, R12.2
unnamed: GAIN-B-CH1.1, R13.1, R14.1
unnamed: C37.1, IC2.3 (+), R19.1, R21.1
unnamed: C36.1, IC2.2 (-), R18.1, R20.2
unnamed: C41.2, IC2.5 (+), R25.1
unnamed: IC2.6 (-), IC2.7, R24.2
unnamed: C58.1, IC4.3 (+), PAN-CH1.2 (WIPER), R38.2
unnamed: IC4.2 (-), R40.1, R42.2
unnamed: C59.1, IC4.5 (+), R39.2
unnamed: IC4.6 (-), R41.1, R43.2
unnamed: IC5.1, R35.2
unnamed: IC5.3 (+), R31.1
unnamed: C53.1, IC5.2 (-), R36.2, R37.1
unnamed: C63.1, IC7.2 (-), R65.2
unnamed: C64.1, IC8.2 (-), R66.1, R67.2
unnamed: C71.1, IC8.6 (-), R68.1, R71.1, R76.2
unnamed: C68.1, IC9.3 (+), R73.1, R74.1
unnamed: C69.1, IC9.2 (-), R72.1, R75.2
unnamed: C80.2, IC11.3 (+), R83.1, R85.1, SW-LEFT-1.2-NO (NO), SW-RIGHT-1.2-C (C)
unnamed: C81.2, IC11.5 (+), R84.1, R86.1, SW-LEFT-1.2-C (C), SW-RIGHT-1.2-NO (NO)
unnamed: INSERT-CH1.1-C (C), R27.1, R89.2
unnamed: INSERT-CH1.1-NO (NO), R22.1
unnamed: C32.1, FB9.2
unnamed: C33.2, FB10.2
unnamed: C86.1, FB11.2
unnamed: C87.2, FB12.2
unnamed: PFL-CH1.1-C (C), R27.2
unnamed: R44.2, ROUTE-CH1.1
unnamed: R46.2, ROUTE-CH1.2
unnamed: R50.2, ROUTE-CH1.3
unnamed: R52.2, ROUTE-CH1.4
unnamed: R62.1, SOLO-CH1.LED-C
unnamed: R63.1, SELECT-CH1.LED-C
unnamed: R64.1, REC-CH1.LED-C
unnamed: C58.2, IC4.1, R38.1, R40.2, ROUTE-CH1.A (C)
unnamed: R45.2, ROUTE-CH1.5 (1)
unnamed: R47.2, ROUTE-CH1.6 (2)
unnamed: R51.2, ROUTE-CH1.7 (3)
unnamed: R53.2, ROUTE-CH1.8 (4)
unnamed: C59.2, IC4.7, R39.1, R41.2, ROUTE-CH1.B (C)
unnamed: R81.2, SW-LEFT-1.1-C (C)
unnamed: SW-LEFT-1.1-NC (NC), SW-RIGHT-1.2-NC (NC)
unnamed: R83.2, SW-LEFT-1.1-NO (NO)
unnamed: SW-LEFT-1.2-NC (NC), SW-RIGHT-1.1-NC (NC)
unnamed: R82.2, SW-RIGHT-1.1-C (C)
unnamed: R84.2, SW-RIGHT-1.1-NO (NO)
RIGHT-OUT: IC11.6 (-), IC11.7, R88.2

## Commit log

2026-05-02 added pcb
    [Console.kicad_pcb, Console.kicad_sch, appunti.kicad_sch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]
2026-05-02 relay instead of switch
2026-05-14 modifiche sostanziali al path
    [input-jacks.kicad_sch, mono_channel.kicad_sch]
2026-05-14 altre cose
    [fader.kicad_sch, mono_channel.kicad_sch]
2026-05-15 fx bypass
    [mono_channel.kicad_sch]
2026-05-15 bom fix
2026-05-15 bom addition
2026-05-17 fix varie
    [appunti.kicad_sch, mono_channel.kicad_sch]
2026-05-17 fix bom
